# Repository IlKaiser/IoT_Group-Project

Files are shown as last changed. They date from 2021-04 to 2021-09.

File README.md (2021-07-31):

# Safety Floater

## Team Members

The team is composed by:
- Daniele Bufalieri [Linkedin Profile](https://www.linkedin.com/in/daniele-bufalieri-4b245a121/)
- Marco Calamo  [Linkedin Profile](https://www.linkedin.com/in/marco-calamo-9766751a3/)
- Ivan Giacomoni [Linkedin Profile](https://www.linkedin.com/in/ivan-giacomoni-53100420a/)

## Main Idea

**Safety Floater** is a smart floater with the purpose to detect the **illegal transit** of the **boats** near by swimmers, in order to preserve the safe distance. This system allows to the authorities to monitor coasts and tourists' welfare. At the same time, Safety Floater allows achieve another goal in an indirect way: improve the water pollution near the coast.

In future, the system could be used to monitor the state of the sea and to improve the prevention of the illegal traffic of boats by installing a camera in order to get a photo of who break the rules.

## Documents

- [Concept](https://github.com/IlKaiser/IoT_Group-Project/blob/main/concept.md)
- [Technology](https://github.com/IlKaiser/IoT_Group-Project/blob/main/technology.md)
- [Evaluation](https://github.com/IlKaiser/IoT_Group-Project/blob/main/evaluation.md)

## Circuit

More informations about the **circuit** and the whole **wiring of components** can be found [here](https://github.com/IlKaiser/IoT_Group-Project/blob/main/circuit/README.md).

## Setup

More informations about the **setup** of the project can be found [here](https://github.com/IlKaiser/IoT_Group-Project/blob/main/setup.md).

## Code

- **Nucleo code**: more info about the Nucleo code can be found [here](https://github.com/IlKaiser/IoT_Group-Project/blob/main/nucleo_code/README.md).
- **Arduino code**: more info about the Arduino code can be found [here](https://github.com/IlKaiser/IoT_Group-Project/blob/main/arduino_code/README.md).
- **Raspberry code**: more info about the Raspberry code can be found [here](https://github.com/IlKaiser/IoT_Group-Project/blob/main/raspberry_code/Code.md).
- **Convolutional Neural Network code**: more info about the Convolutional Neural Network code can be found [here](https://github.com/IlKaiser/IoT_Group-Project/blob/main/ML/MR-SSD.md).

## Web Dashboard

More informations about the **Web Dashboard** can be found [here](https://github.com/IlKaiser/IoT_Group-Project/blob/main/dashboard/README.md).

## Evaluation on Iot-lab

More informations about the **evaluation** conducted on [Iot-lab](https://www.iot-lab.info/) can be found [here](https://github.com/IlKaiser/IoT_Group-Project/blob/main/evaluation/README.md).

## Videos

- [Presentation of the project](https://www.youtube.com/watch?v=rqtzGxGxrBQ)
- [Demo](https://youtu.be/sozL5CH4RoQ)

## Blog post

[Blog post](https://medium.com/@danielebufalieritkd/safety-floater-1a63ddf3e4a9)

## Releases

- [First delivery](https://github.com/IlKaiser/IoT_Group-Project/releases/tag/1.0): for the first delivery you can also check this set of [slides](https://github.com/IlKaiser/IoT_Group-Project/blob/main/Safety%20floater.pptx)
- [Second delivery](https://github.com/IlKaiser/IoT_Group-Project/releases/tag/2.0): for the second delivery you can find more info [here](https://github.com/IlKaiser/IoT_Group-Project/blob/main/2nd_delivery.md), and you can also check this set of [slides](https://github.com/IlKaiser/IoT_Group-Project/blob/main/Safety%20floater_2nd_delivery.pptx)
- [Third delivery](https://github.com/IlKaiser/IoT_Group-Project/releases/tag/3.0): for the third delivery you can also check this set of [slides](https://github.com/IlKaiser/IoT_Group-Project/blob/main/Safety%20floater_final_delivery.pptx)

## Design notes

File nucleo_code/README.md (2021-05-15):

# Nucleo code

## Starting the application
The application starts by initializing the I2C interface. In order to do this, we need to add the *periph_i2c* feature in the [Makefile](https://github.com/IlKaiser/IoT_Group-Project/blob/main/nucleo_code/Makefile):

### I2C initialization

```c
FEATURES_REQUIRED += periph_i2c
```

Also, we need to include the following **headers** in the [main.c](https://github.com/IlKaiser/IoT_Group-Project/blob/main/nucleo_code/main.c):

```c
#include "periph_conf.h"
#include "periph/i2c.h"
```

Also we have to define the I2C interface:

```c
#define I2C_INTERFACE I2C_DEV(0)
```

Below we report the code related to the initialization of the I2C interface:

```c
//initialize the i2c interface
i2c_init(I2C_INTERFACE);
```
### I2C communication
Finally, the I2C communication is managed by the *I2CCommunication* function:

```c
void I2CCommunication(int cmd,void*buffer,int len,char* service){
    mutex_lock(&mutex);
    while(i2c_acquire(I2C_INTERFACE)<0)
	printf("[%s]ERROR ACQUIRING \n",service);
    if(i2c_write_byte(I2C_INTERFACE,ARDUINO_ADDRESS,cmd,0)<0)
	printf("[%s] ERROR WRTITING \n",service);
    if(i2c_read_bytes(I2C_INTERFACE,ARDUINO_ADDRESS,buffer,len,0)<0)
	printf("[%s] READING \n",service);
    i2c_release(I2C_INTERFACE);
    mutex_unlock(&mutex);	
}
```

As we can see we need to define the **Arduino address** in the [main.c](https://github.com/IlKaiser/IoT_Group-Project/blob/main/nucleo_code/main.c):

```c
#define ARDUINO_ADDRESS (0X04)
```

Notice how the access to the I2C bus is treated as a **critical section**, because we have to avoid that multiple threads access it at the same time. In order to do this, we used a **mutex**, so we have to include the following **header** in the [main.c](https://github.com/IlKaiser/IoT_Group-Project/blob/main/nucleo_code/main.c):

```c
#include "mutex.h"
```

We define the mutex as follows:

```c
//define mutex to protect i2c access
mutex_t mutex;
```

### Threads
Then we create three different threads, one for each sensor we used:

```c
thread_create(stackThreadAlarm,sizeof(stackThreadAlarm),THREAD_PRIORITY_MAIN,0,threadAlarm,NULL,"Thread Alarm detection");
	printf("Thread proximity alarm created! \n");
	
thread_create(stackThreadControl,sizeof(stackThreadControl),THREAD_PRIORITY_MAIN,0,threadControl,NULL,"Thread Control");
	printf("Thread control created! \n");
	
thread_create(stackThreadInfo,sizeof(stackThreadInfo),THREAD_PRIORITY_MAIN,0,threadInfo,NULL,"Thread Info ");
	printf("Thread info created! \n");
```

In order to do this we need to include this **header** in the [main.c](https://github.com/IlKaiser/IoT_Group-Project/blob/main/nucleo_code/main.c):

```c
#include "thread.h"
```

## Pins initialization
All pins used are initialized by using the **GPIO peripheral driver**, that maps each pin to a **port** with a certain **port number**. Particularly, all mappings are shown in the picture below:

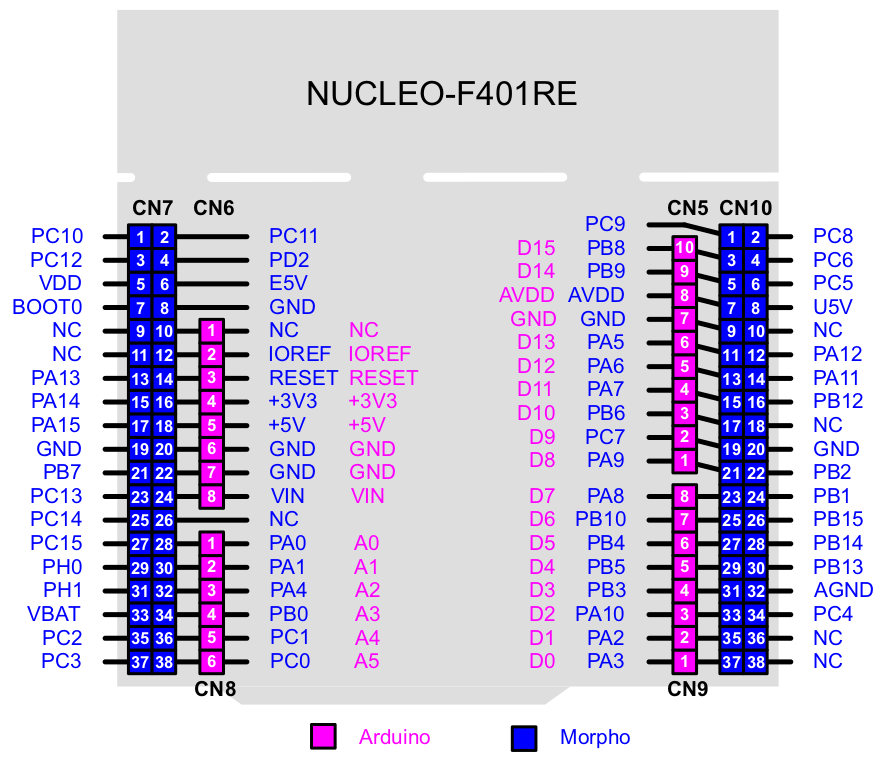
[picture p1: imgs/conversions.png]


## Alarm thread

This thread initializes the **buzzer**, and then starts periodically requesting the Arduino info about the current situation nearby the floater by the **I2C communication**. If the Nucleo receives a number of indications of a possible violation greater or equal than a certain **ALARM_THRESHOLD**, then the buzzer starts to sound and a **notification** that a boat was found is sent to the Arduino by the I2C communication.
The buzzer is initialized in this way:

### Alarm thread: buzzer

```c
//definition and initialitation of buzzer using pin D9
gpio_t buzzer;

buzzer=GPIO_PIN(PORT_C,7);
if(gpio_init(buzzer,GPIO_OUT)<0){
    printf("[ALARM]Error during buzzer initialitation!\n");
    return NULL;
}
```

It is managed by the *controlBuzzer* function:

```c
void controlBuzzer(gpio_t buzzer,int status){
    if(status==0)
	gpio_clear(buzzer);
    else if(status==1)
	gpio_set(buzzer);
}
```

### Alarm thread: periodical sampling

The periodical requests are done by using the **xtimer** module, so we need to specify it in the [Makefile](https://github.com/IlKaiser/IoT_Group-Project/blob/main/nucleo_code/Makefile):

```c
USEMODULE += xtimer
```

Also, we need to include this **header** in the [main.c](https://github.com/IlKaiser/IoT_Group-Project/blob/main/nucleo_code/main.c):

```c
#include "xtimer.h"
```

We define the **base sampling period** for the Alarm thread as follows:

```c
#define DELAY_ALARM_BASE 1

int delay_alarm = DELAY_ALARM_BASE;
```

### Alarm threshold
The **alarm threshold** is defined as follows:

```c
#define ALARM_THRESHOLD 2
```

### Alarm thread: I2C communication
Given that the *I2CCommunication* function takes as input the **command** related to the specific request for the Arduino, the **buffer** for receiving data from the I2C bus, the **length** of the buffer and the specific **service**, we need to specify the **command** and **buffer length** for both cases of use of the I2C communication by the Alarm thread:

```c
#define ALARM_BUFFER_SIZE 1
#define ALARM_CMD 1
#define BOAT_FOUND_CMD 5
```

### Alarm thread: periodical requests
So, the **periodical request** of the alarm thread is resumed in the following code:

```c
int cont=0;
char buffer[ALARM_BUFFER_SIZE]={0};
	
while(1){
	I2CCommunication(ALARM_CMD,buffer,ALARM_BUFFER_SIZE,"ALARM");
	printf("[ALARM]MEX: %s \n",buffer);
		
	if(atoi(buffer)==1)
		cont++;
	else
		cont=0;

	if(cont==ALARM_THRESHOLD){
		controlBuzzer(buzzer,1);
		I2CCommunication(BOAT_FOUND_CMD,buffer,ALARM_BUFFER_SIZE,"BOAT FOUNDs");
	}
	if(cont==0)
		controlBuzzer(buzzer,0);
		
	xtimer_sleep(delay_alarm);
	
}
```

## Control thread

### Control thread: MPU-9250 initialization
The thread first initialize the **MPU9250 sensor**, then periodically samples it in order to check, together with the Arduino, whether the **proximity sensor** needs to be better oriented or not, and also to manage the **power consumption** in a smart way.
In order to use the MPU9250 sensor we have to specify the **mpu9250 module** in the [Makefile](https://github.com/IlKaiser/IoT_Group-Project/blob/main/nucleo_code/Makefile):

```c
# MPU-9250 driver
DRIVER ?= mpu9250
USEMODULE += $(DRIVER)
```

Also, we need to include some **utilities** in the [Makefile](https://github.com/IlKaiser/IoT_Group-Project/blob/main/nucleo_code/Makefile):

```c
# utilities for MPU 
ifneq (,$(wildcard $(CURDIR)../../RIOT/tests*/.))
  DEFAULT_MODULE += test_utils_interactive_sync
  # add interactive test configuration when testing Kconfig
  ifeq (1,$(TEST_KCONFIG))
    KCONFIG_ADD_CONFIG += $(RIOTBASE)/tests/test_interactive.config
  endif
endif

ifneq (,$(filter tests_driver_%,$(APPLICATION)))
  BOARD ?= nucleo-f401re
endif
```

Also, we need to include the following **headers** in the [main.c](https://github.com/IlKaiser/IoT_Group-Project/blob/main/nucleo_code/main.c):

```c
#include "mpu9x50.h"
#include "mpu9x50_params.h"
```

Then we have to specify the **buffer length** for the control thread for the I2C communication with Arduino:

```c
#define CONTROL_BUFFER_SIZE 10
```

The MPU9250 is initialized as follows:

```c
char buffer[CONTROL_BUFFER_SIZE]={0};
		
// definition of MPU-device
mpu9x50_t dev;
int result;

// MPU device initialization
result = mpu9x50_init(&dev, &mpu9x50_params[0]);
    
// Check errors
if (result == -1) {
    puts("[MPU9250] The given i2c is not enabled");
    return NULL;
}
else if (result == -2) {
    puts("[MPU9250] The compass did not answer correctly on the given address");
    return NULL;
}
   
// Definition of sample rates
mpu9x50_set_sample_rate(&dev, 200);
if (dev.conf.sample_rate != 200) {
    puts("[MPU9250] The sample rate was not set correctly");
    return NULL;
}
    
mpu9x50_set_compass_sample_rate(&dev, 100);
    
if (dev.conf.compass_sample_rate != 100) {
    puts("[MPU9250] The compass sample rate was not set correctly");
    //return NULL;
}
```

### Control thread: periodical sampling
We define the **base sampling period** for the Control thread as follows:

```c
#define DELAY_CONTROL_BASE 100

int delay_control = DELAY_CONTROL_BASE;
```

So, the **periodical sampling** of the control thread is resumed in the following code:

```c
short x_start_compass = 0;
	
//sample values for magnetic field detected by the compass and accelerometer
short z_gyro, x_compass, z_accel;
	
getControlData(dev, &z_gyro, &x_start_compass, &z_accel);
		
int last_state = 0;  // It stands for 'the proximity sensor is correctly orientated'

while(1){
	//get control data correction degree will be saved into buffer with sintax -360/360 as char*
	getControlData(dev, &z_gyro, &x_compass, &z_accel);
				
	// Proximity sensor correction
	proximitySensorCorrection(buffer, x_start_compass, x_compass, z_gyro, &last_state);
		
	// Power management
	float z_accell = ( (float) z_accel ) * GRAVITY_ACCELERATION / 1000;
	powerManagement(z_accell);
		
	xtimer_usleep(delay_control);
}
```

### Control thread: getControlData function
As we can see, data from MPU9250 are retrieved by using the *getControlData* function. Below we show the code related to this function:

```c
void getControlData(mpu9x50_t dev, short* z_gyro, short* x_compass, short* z_accel)
{
	//Data structure to save info
	mpu9x50_results_t measurement;
    
	mutex_lock(&mutex);
	
	/* Get accel data in milli g */
        mpu9x50_read_accel(&dev, &measurement);
        *z_accel = measurement.z_axis;
        //printf("[MPU9250] Accel data [milli g] - X: %"PRId16"   Y: %"PRId16"   Z: %"PRId16"\n",
        //        measurement.x_axis, measurement.y_axis, measurement.z_axis);
        /* Get gyro data in dps */
        mpu9x50_read_gyro(&dev, &measurement);
        *z_gyro = measurement.z_axis;
        //printf("[MPU9250] Gyro data [dps] - X: %"PRId16"   Y: %"PRId16"   Z: %"PRId16"\n",
        //        measurement.x_axis, measurement.y_axis, measurement.z_axis);
        /* Get compass data in mikro Tesla */
        
        while(!first_read_compass_done){
			
		mpu9x50_read_compass(&dev, &measurement);
		*x_compass = measurement.x_axis;
		    
		if(*x_compass != 0){
			first_read_compass_done = 1;
			break;	
		}	
	}
		
	if(first_read_compass_done){
		mpu9x50_read_compass(&dev, &measurement);
		*x_compass = measurement.x_axis;	
	}

	mutex_unlock(&mutex);
	
}
```

Notice that each sampling from the MPU9250 is treated as a **critical section**, because the sensor communicates with the Nucleo board by I2C, so we have to use the **mutex** in order to avoid **starvations** of other threads.

### Control thread: proximitySensorCorrection function

```c
void proximitySensorCorrection(char* buffer, short x_start_compass, short x_compass, short z_gyro, int* last_state){
    float degree = calculateDegreeFromDps(z_gyro, FIXED_NUMBER);
    
	short x_diff_compass = x_start_compass - x_compass;	
	int x_diff_compass_abs = abs((int)x_diff_compass);
	
	// If the proximity sensor is NOT correctly orientated
	if(x_diff_compass_abs > CORRECTION_THRESHOLD){
		
		// If it was correctly orientated before this point
		if(*last_state == 0){
		    
		    // If it is moving to the left 
		    if(degree > 0){
			    
			    // Setting the last state to 1, which means that the "next" last state will be that
			    // the proximity sensor was moved to the right
			    *last_state = 1;
			    // Send to Arduino the indication to move it to the right
			    I2CCommunication(CONTROL_CMD_RIGHT, buffer, CONTROL_BUFFER_SIZE, "CONTROL");
			        	
			}
			
			// If it is moving to the right
			else if(degree < 0){
			    
			    // Setting the last state to 2, which means that the "next" last state will be that
			    // the proximity sensor was moved to the left
			    *last_state = 2;
			    // Send to Arduino the indication to move it to the left
			    I2CCommunication(CONTROL_CMD_LEFT, buffer, CONTROL_BUFFER_SIZE, "CONTROL");
			        	
			} 
		    	
		}
		
		// If it was moved to the rigth before this point
		else if(*last_state == 1){
			
		    // Send to Arduino the indication to move it to the right
			I2CCommunication(CONTROL_CMD_RIGHT, buffer, CONTROL_BUFFER_SIZE, "CONTROL");
		}
		
		// If it was moved to the left before this point
		else if(*last_state == 2){
			
		    // Send to Arduino the indication to move it to the left
			I2CCommunication(CONTROL_CMD_LEFT, buffer, CONTROL_BUFFER_SIZE, "CONTROL");
		}
		
	}
	
	// The proximity sensor is correctly orientated
	else{
		*last_state = 0;
	    //printf("The proximity sensor is correctly orientated\n"); 
	}
		
}
```

The main idea of the proximity sensor orientation correction is measuring the first value of the **magnetic field (in µT)** along the **x-axis** of the **compass**, and continuosly check whether the current value measured is too far from the starting value, for example by exploiting a **correction threshold**, that we define in the [main.c](https://github.com/IlKaiser/IoT_Group-Project/blob/main/nucleo_code/main.c) as follows:

```c
#define CORRECTION_THRESHOLD 1
```

If the current orientation of the proximity sensor is too far from the starting one, then we send to Arduino by I2C the indication to rotate the sensor in the opposite direction from the currently detected motion, that is detected by the the measurement of the **dps (degree per seconds)** along the **z-axis** of the **gyroscope**. This procedure is repeated until the proximity sensor is not correctly orientated again. We have also to define, in the [main.c](https://github.com/IlKaiser/IoT_Group-Project/blob/main/nucleo_code/main.c), the two commands for the I2C communication, indicating a correction towards the right or the left:

```c
#define CONTROL_CMD_RIGHT 2
#define CONTROL_CMD_LEFT 3
```

### Control thread: power management

The **power management** is handled by the sampling of the **acceleration** measured along the **z-axis** of the **accelerometer**:

- if the acceleration is below a **low threshold**, then sampling delays are setted to the base delays
- if the acceleration is above a **low threshold** but below an **high threshold**, then sampling delays are slightly increased
- if the acceleration is above a **high threshold**, then sampling delays are further increased

So we have to define the **thresholds** in the [main.c](https://github.com/IlKaiser/IoT_Group-Project/blob/main/nucleo_code/main.c):

```c
#define LOW_PM_THRESHOLD 9.5
#define HIGH_PM_THRESHOLD 10.0
```

Also, we have to define all **delays** in the [main.c](https://github.com/IlKaiser/IoT_Group-Project/blob/main/nucleo_code/main.c):

```c
//medium time interval for each thread
#define DELAY_INFO_MEDIUM 50
#define DELAY_ALARM_MEDIUM 10
#define DELAY_CONTROL_MEDIUM 10000000

//high time interval for each thread
#define DELAY_INFO_HIGH 70
#define DELAY_ALARM_HIGH 20
#define DELAY_CONTROL_HIGH 60000000
```

All this is done by the *powerManagement* function:

```c
void powerManagement(float z_accel){
    if(z_accel <= LOW_PM_THRESHOLD){
		printf("ACCEL LOW!\n");
		    
		delay_alarm = DELAY_ALARM_BASE;
		delay_control = DELAY_CONTROL_BASE;
		delay_info = DELAY_INFO_BASE;	
    }
    
    else if(z_accel > LOW_PM_THRESHOLD && z_accel <= HIGH_PM_THRESHOLD){
		printf("ACCEL MEDIUM!\n");
		    
		delay_alarm = DELAY_ALARM_MEDIUM;
		delay_control = DELAY_CONTROL_MEDIUM;
		delay_info = DELAY_INFO_MEDIUM;	
    }
		
    else if(z_accel > HIGH_PM_THRESHOLD){
		printf("ACCEL HIGH!\n");
		    
		delay_alarm = DELAY_ALARM_HIGH;
		delay_control = DELAY_CONTROL_HIGH;
		delay_info = DELAY_INFO_HIGH;	
     }
}
```

## Info thread

This thread periodically requests the Arduino for the **last known position** of the floater. In the [main.c](https://github.com/IlKaiser/IoT_Group-Project/blob/main/nucleo_code/main.c), we need to define the **base sampling period** for the Info thread as follows:

```c
#define DELAY_INFO_BASE 30

int delay_info = DELAY_INFO_BASE;
```

Also, in the [main.c](https://github.com/IlKaiser/IoT_Group-Project/blob/main/nucleo_code/main.c), we need to define the **buffer length** for the I2C communication with Arduino, as well as the **info command**:

```c
#define INFO_BUFFER_SIZE 20
#define INFO_CMD 4
```

### Info thread: periodical requests
So, the **periodical requests** of the **Gps** informations done by the Info thread are resumed in the following code:
```c
char buffer[INFO_BUFFER_SIZE]={0};
while(1){	
	
	I2CCommunication(INFO_CMD,buffer,INFO_BUFFER_SIZE,"INFO");
		
	char* first = getSubstr(buffer, 0, 2);
		
	if(strcmp(first, "/") == 0){
		printf("[INFO] No info received!\n");
	}
		
	else{
		printf("[INFO] %s\n",buffer);
	}
			
	xtimer_sleep(delay_info);
	
}
```

Obviosuly, gps info could not be immediately available.

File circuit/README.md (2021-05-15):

# Wiring of components
For the project we will use:
- an [STM32 Nucleo-64 F401RE](https://www.st.com/en/evaluation-tools/nucleo-f401re.html) board
- an [Arduino Uno](https://store.arduino.cc/arduino-uno-rev3) board
- a [Raspberry Pi 4](https://www.raspberrypi.org/products/raspberry-pi-4-model-b/) board
- 1 HC-SR04 ultrasonic proximity sensor
- an MPU-9250 9 Axis Gyroscope Accelerometer Magnetic Field sensor
- a BN-880 gps module
- a Raspberry pi Camera Rev 1.3
- 1 buzzer
- 1 100 Ohm resistor
- 1 Stepper Unipolar motor
- 1 ULN2008
- 1 HC-05

First, we need to put the **5v supply** and the **ground** on the breadboard.

In order to establish the **I2C** communication between the Nucleo board and the Arduino Uno board, we need to:
- connect one **GND pin** of the Arduino Uno board with one **GND pin** of the Nucleo board
- the **A5 pin** of the Arduino Uno board with the **SCL/D15 pin** of the Nucleo board
- the **A4 pin** of the Arduino Uno board with the **SDA/D14 pin** of the Nucleo board

However, since the SCL and SDA pins are also needed for the MPU-9250 sensor, we need to put them on the breadboard.

Now we explain the wiring of sensors and actuators:
- For the **buzzer**, we have to use a **resistor of 100 Ohm**, and we need to connect the **positive pin** of the buzzer to a **digital pin** of the Nucleo board, while the **negative pin** will be connected to one side of the resistor, and finally the other side of the resistor will be connected to **ground**: particularly, the digital pin of the Nucleo board we connect the buzzer is the **D9 pin**
- For the **HC-SR04** sensor we need to connect the **GND pin** to **ground** on the breadboard, the **VCC pin** to **5V** on the breadboard, the **trig pin** to the **D12 pin** of the Arduino Uno board and the **echo pin** to the **D13 pin** of the Arduino Uno board
- For the **MPU-9250** sensor we need to connect the **GND pin** to **ground** on the breadboard, the **VCC pin** to **3.3V** of the Nucleo board, the **SCL pin** to the **SCL/D15 pin** of the Nucleo board on the breadboard and the **SDA pin** to the **SDA/D14 pin** of the Nucleo board on the breadboard
- For the **BN-880** module we need to to connect the **GND pin** to **ground** on the breadboard, the **VCC pin** to **5V** on the breadboard and the **TX pin** to the **D7 pin** of the Arduino Uno board
- For the **HC-05** Bluetooth module we need to connect the **GND pin** to **GND** on Arduino, the **VCC pin** to **5V** of the Arduino board, the **RX pin** to the **D2 pin** of the Arduino board,the **TX pin** to the **D3 pin** of the Arduino board 

Below we can see the **wiring of components** for the Nucleo board and the Arduino Uno board:

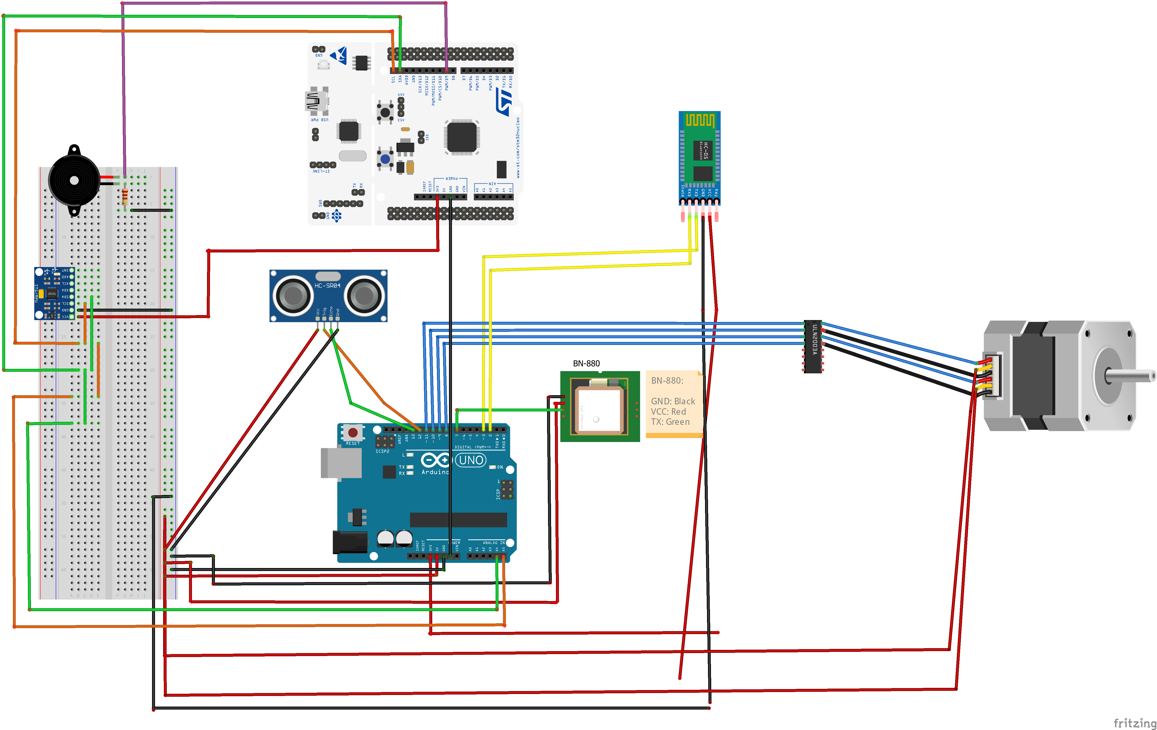
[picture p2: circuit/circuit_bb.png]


**NOTE!** As you can see from the wiring, we need to point out a few things: 
- the MPU sensor is not an MPU-9250 in the picture, but is an MPU-6050 sensor, that works with the same logic
- in the picture we have a 220 Ohm resistor but, as mentioned before, it should be a 100 Ohm resistor

Below we can see the **wiring of components** for the Raspberry board:

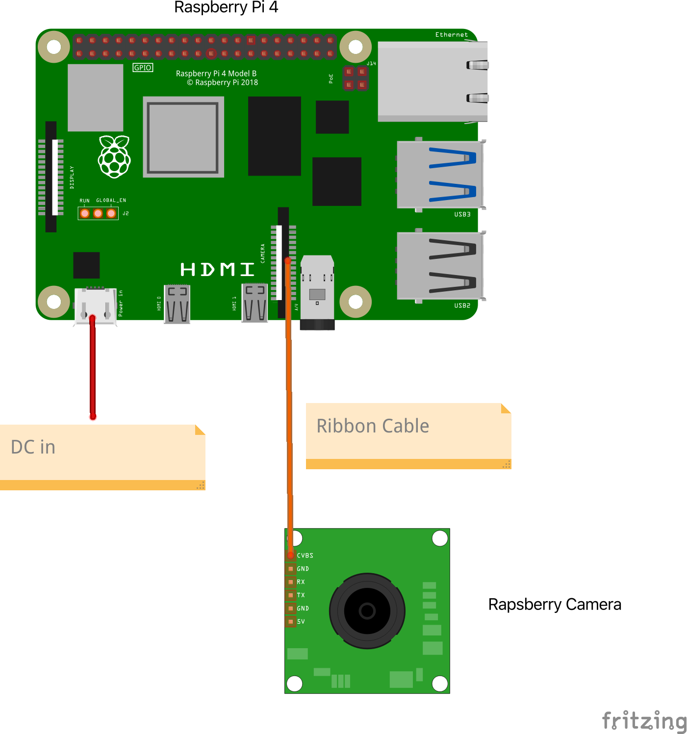
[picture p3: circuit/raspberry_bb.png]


No special wiring is required, the ribbon cable included with the camera needs to be installed in correct way in the camera slot.
Since the Raspberry will be in **Headless Mode** (will be entirely controlled remotely) only a generic 15W USB Type-C power supply is required.

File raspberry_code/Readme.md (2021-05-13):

# Raspberry Setup

## Before you start 
- Make sure you download the prebuilt .h5 model for machine learning from [here](https://drive.google.com/file/d/1-JYH7f6np6WcKjgFJ4iTFM7xC8h3vFz8/view?usp=sharing), you rename it **model.h5**
and you place it in the model folder
- Make sure to get aws **root certificate** (rootCA.pem), your **certificate** (cert.pem) and **private key** (private.key) for IoT Core and place it in certificates folder (more info [here](https://docs.aws.amazon.com/iot/latest/developerguide/iot-moisture-create-thing.html))
- Install pip requirements

## Install pip requirements
Run:
```
pip3 install -r requirements.txt
```
to automatically install all needed modules.
If you have issue installing tensorflow follow this [guide](https://qengineering.eu/install-tensorflow-2.4.0-on-raspberry-64-os.html), delete tensorflow from requirements and run the command again.

## Before you execute the program
### Bluetooth setup
Execute:
```
sudo rfcomm connect 0 <MAC of Bt adapter>
```
to connect the Arduino Bluetooth-Adapter tio Raspberry and Setup hc-05 serial protocol.

## Start program
```
python3 main.py
```
more info on the code [here](./Code.md).

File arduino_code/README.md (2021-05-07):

# Arduino code

## Libraries

- **Wire.h**: used to send messagges over the I2C bus towards the Nucleo board
- **Stepper.h**: used to manage the Stepper motor
- **TinyGPS.h**: used to parse data received from the gps module
- **SoftwareSerial.h**: used for the serial connection with the GPS device and the Bluetooth module

In order to use them, we need to include them on the top of the [sensors.ino](https://github.com/IlKaiser/IoT_Group-Project/blob/main/arduino_code/sensors.ino):

```cpp
#include <Wire.h>
#include <Stepper.h>
#include <TinyGPS++.h>
#include <SoftwareSerial.h>
```

## Macro

- **trigPin**: it specifies the trig pin of the HCSR04 ultrasonic proximity sensor, whose purpose is to trigger the ultrasound
- **echoPin**: it specifies the echo pin of the HCSR04 ultrasonic proximity sensor, whose purpose is to receive the signal back from the object detected
- **SMART_DELAY_GPS**: it indicates (in ms) the delay after which the gps object tries to read new data
- **STEPS**: number of steps performed by the Stepper motor
- **MAX_DISTANCE_FROM_FLOATER**: under this threshold (in cm), the Arduino board send a notification of a possible detection to the Nucleo board

So we need do define these constants in the [sensors.ino](https://github.com/IlKaiser/IoT_Group-Project/blob/main/arduino_code/sensors.ino):

```cpp
#define trigPin                       12
#define echoPin                       13
#define SMART_DELAY_GPS               50
#define STEPS                         48
#define MAX_DISTANCE_FROM_FLOATER     170   
```

## Global variables

- **mode**: auto or test, default is auto
- **ID**: the floater id
- **x**: a byte used to discriminate between the different type of requests recieved by the Nucleo board
- **durata, cm**: used to store, respectively, the time it takes for the impulse to go and return and the distance (in cm) measured.
- **RXPin, TXPin**: RXPin and TXPin for the GPS
- **infoGps**: used to store info retrieved from the bn-880n gps module
- **ss**: SoftwareSerial instance for the serial connection to the GPS device
- **EEBlue**: SoftwareSerial instance for the serial connection to the Bluetooth module
- **gps**: the TinyGPS++ object
- **stepper**: instance of the stepper class

So we need do define these global variables in the [sensors.ino](https://github.com/IlKaiser/IoT_Group-Project/blob/main/arduino_code/sensors.ino):

```cpp
String mode = "auto";
String ID="1";
byte x = 0;
long durata, cm;
static const int RXPin = 7, TXPin = 3;
static const uint32_t GPSBaud = 9600;
String infoGps;
SoftwareSerial ss(RXPin, TXPin);
SoftwareSerial EEBlue(3, 2);
TinyGPSPlus gps;
Stepper stepper(STEPS, 8, 10, 9, 11);
```

## Setup function
We need to set the **Arduino address** in order to correctly establish the I2C communication with the Nucleo board:

```cpp
Wire.begin(0x04);
```

Then we need to set the **data rate** of both serial connections to **9600 bps**:

```cpp
EEBlue.begin(9600);
ss.begin(9600);
```

Then we need to specify that whenever on the I2C bus there is some data to read, we need to handle this event by executing the *receiveEvent* function:

```cpp
Wire.onReceive(receiveEvent);
```

Also, we need to specify that whenever the Nucleo board makes a specific request to the Arduino, we need to handle this event by executing the *requestEvent* function:

```cpp
Wire.onRequest(requestEvent);
```

Then we need to initialize the **pins** for the **HCSR04** sensor:

```cpp
pinMode(trigPin, OUTPUT);
pinMode(echoPin, INPUT);
```

## Loop function
The loop function is used only to periodically update (by using the *smartDelay* function) the **position** of the floater, by using the *getGpsInfo* function. Below I report these two functions:

```cpp
String getGpsInfo(){
  if(gps.location.isValid() && gps.speed.isValid()){

    float lat = gps.location.lat(), lon = gps.location.lng(), speed_kmh = gps.speed.kmph();
   
    String lat_s = fromFloatToString(lat, 4);
    String lon_s = fromFloatToString(lon, 4);
    float speed_ms = speed_kmh / 3.6;

    String info = "";
    info += String(lat_s);
    info += ";";
    info += String(lon_s);
    info += ";";
    info += String(speed_ms);
    
    return info;
  }

  else{
      return "/";
  }
}

static void smartDelay(unsigned long ms)
{
  unsigned long start = millis();
  do 
  {
    while (ss.available())
      gps.encode(ss.read());
  } while (millis() - start < ms);
}
```

## receiveEvent function
This function just store the type of request received by the Nucleo board that has to be done:

```cpp
void receiveEvent(int data){
  x = Wire.read();
}
```

## requestEvent function
This function manages the vaious type of requests received by the Nucleo board, with the possibility to use an **automatic** and a **test** mode. By looking the auto mode, we present the various type of requests' management.

### Boat detection (x==1)
By using the HCSR04 sensor, we send to the Nucleo board an indication of a **possible detection** if we are below the **MAX_DISTANCE_FROM_FLOATER** threshold, otherwise an indication that everything is ok. Below we report the code:

```cpp
if(x == 1){
        
        measureDistanceBy_HCSR04();
  
        Serial.print("Cm = ");
        Serial.println(cm);
        Serial.println();

        if(cm <= MAX_DISTANCE_FROM_FLOATER){
          Serial.println("Possible detection!");
          Wire.write("1");  
        }

        else{
          Serial.println("No boats detected!");
          Wire.write("0");    
        }

}
```

Also, we report the *measureDistanceBy_HCSR04* function:

```cpp
void measureDistanceBy_HCSR04(){
   
   digitalWrite(trigPin, LOW);
   delayMicroseconds(2);
   digitalWrite(trigPin, HIGH);
   delayMicroseconds(10);
   digitalWrite(trigPin, LOW);
   durata = pulseIn(echoPin, HIGH);
   cm = durata / 58;    // for inches the formula is duration / 148;
   
}
```

### Proximity sensor correction (x==2 || x==3)
By using the Stepper motor, we apply a **correction** of the proximiy sensor orientation towards the **right** if x is 2, otherwise towards the **left** if x is 3. Below we report the code for the correction towards the right, because the other one is similar:

```cpp
else if(x == 2){
        Serial.println("Received 2");

        int direction_ = -1, speed_ = 0;
        int val = 1023;

        speed_ = map(val, 0, 1023, 2, 500);
        // set the speed of the motor
        stepper.setSpeed(speed_);

        // move the stepper motor

        stepper.step(direction_);

        Wire.write("123");
        
}
```

### GPS (x==4)
By using the GPS module, we send to the Nucleo board, if available, the **last known position** of the floater. Below we show the code:

```cpp
else if (x == 4){
        if(infoGps == "/"){
          Wire.write("/");  
        }
    
        else{
          Wire.write(infoGps.c_str());  
        }
}
```

### Bluetooth (x==5)
By using the Bluetooth module, we send to Raspberry pi, if available, the **last known position** of the floater. Below we show the code:

```cpp
else if (x==5){
        if(infoGps!="/"){
          String toSend=infoGps+";"+ID;
          EEBlue.write(toSend.c_str());
        }
        else{
          EEBlue.write(ID.c_str());
        }
        Wire.write(x);
          
}
```

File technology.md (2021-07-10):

# Technology

## Core: Three main parts
- Safety Floater
- Sea Station
- Web Dashboard

### Safety Floater
It is the main component of our project: its main purpose is to detect **illegal transit of boats** over the safety line. When a violation is detected, the sensors data are sent to the **Sea Station (Ground server)**.
A **ultrasonic proximity sensor** is used for detections, a **gyroscope/compass** and a **stepper motor** grant that the floater has the proximity sensor correctly oriented, an **accelerometer** is used to provide a power management mechanism, **gps sensor** detects the current position of the floater, **solar panels** permit a longer battery life and **buzzer** is used for audio notification of swimmers.
A **LoraWan module** would be used in real life scenario to transmit data (its model in practice is a common **bluetooth module**).
The sensors are controlled by a [Nucleo Board](https://www.st.com/en/evaluation-tools/nucleo-f401re.html) (**nucleo-f401re**) with [RIOT OS](https://www.riot-os.org/), and measurements are made with an [Arduino Uno](https://store.arduino.cc/arduino-uno-rev3) board, because we have an easier integration of sensors.
The communication between the two boards is done with the **I2C protocol**: the Nucleo board is the **master**, it periodically asks for sensor data to the Arduino Uno, which is the **slave**. 
For more informations about the circuit, see [here](https://github.com/IlKaiser/IoT_Group-Project/blob/main/circuit/README.md).

### Sea station
It is the **ground server** of our system: it is a content aggregator of many Smart Floaters in a fixed range. It elaborates data from floaters and sends it to the remote server and database. Every Floater has a unique **id** for identification. It also notify the eventual violation to the Coast Guard.
We used a [Raspberry Pi](https://www.raspberrypi.org/products/raspberry-pi-4-model-b/) to take **pictures** of the possible violation, for a further evaluation with a **Convolutional Neural Network** in order to make sure whether there is an actual boat over the safety line or not. If an actual violation is detected, all data from the Floater are sent to **AWS** via **MQTT**.

### Web Dashboard
It is the highest level component of our project. It is composed by the **remote server** (using **AWS services and nodejs**) and by the frontend (web page realized with **HTML, Bootstrap, Javascript and Vue-JS**, and eventually an app). It displays the datas retrived from database (**DynamoDB**).

## Sensors
We chose our sensors based on our system requirements.

### MakerHawk MPU-9250 9DOF Module 9 Axis Gyroscope Accelerometer Magnetic Field Sensor


- 9-axis: 3-axis gyroscope + 3-axis accelerometer + 3-axis magnetic field sensor
- Power supply: 3-5v (low dropout internal regulator)
- Communication: standard IIC / SPI communication protocol
- 16-bit AD data output of the 16-bit chip converter
- Acceleration range: ± 2 ± 4 ± 8 ± 16g
- Magnetic field: ± 4800uT
- Using PCB Immersion Gold, soldering process to ensure quality
- Pin spacing: 2.54mm
- Module size: 15mm * 25mm

**Gyroscope/Compass** are used for **movement detection and orientation**, while **accelerometer** for **power management**.

### Ultrasonic Proximity Sensor HC-SR04


- Working Voltage: DC 5V
- Working Current: 15mA
- Working Frequency: 40Hz
- Max Range: 4m
- Min Range: 2cm
- Measuring Angle: 15 degree
- Trigger Input Signal: 10µS TTL pulse
- Echo Output Signal Input TTL lever signal and the range in proportion
- Dimension 45 * 20 * 15mm

It is used for **violation detection**.

### GPS BN-880
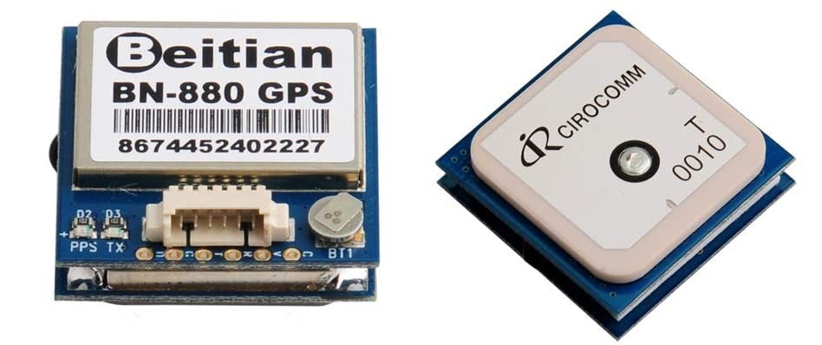
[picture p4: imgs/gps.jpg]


- GPS Module,Dual Module Compass
- With electronic compass IC HMC5883L
- 1.25mm spacing between the 6pins patch seat
- Receiving Format: GPS,GLONASS,Galileo,BeiDou,QZSS and SBAS
- Receiving Channel: 72 Searching Channel
- Output Frequency: 1Hz-10Hz,Default 1Hz
- Support Rate:4800bps to 115200bps,Default 38400dps
- UART Interface: UART Port: TXDA and RXDA
- Level Positioning Precison: 2m At Open Wind
- Speed Precison: 0.1 m/s (Without Aid)
- Acceleration Precison: 0.1 m/s (Without Aid)
- Power Supply: DC Voltage 2.8V~6.0V,Typical:3.3V or 5.0V
- Consumption: Capture 50mA@5V
- Working Temperature:-40℃-+85℃
- Storage Temperature:-40℃-+85℃
- Size:28mm x 28mm x 10mm
- Weight:10g

It is used for getting the last known **position** of the floater.

### Raspberry pi Camera Rev 1.3

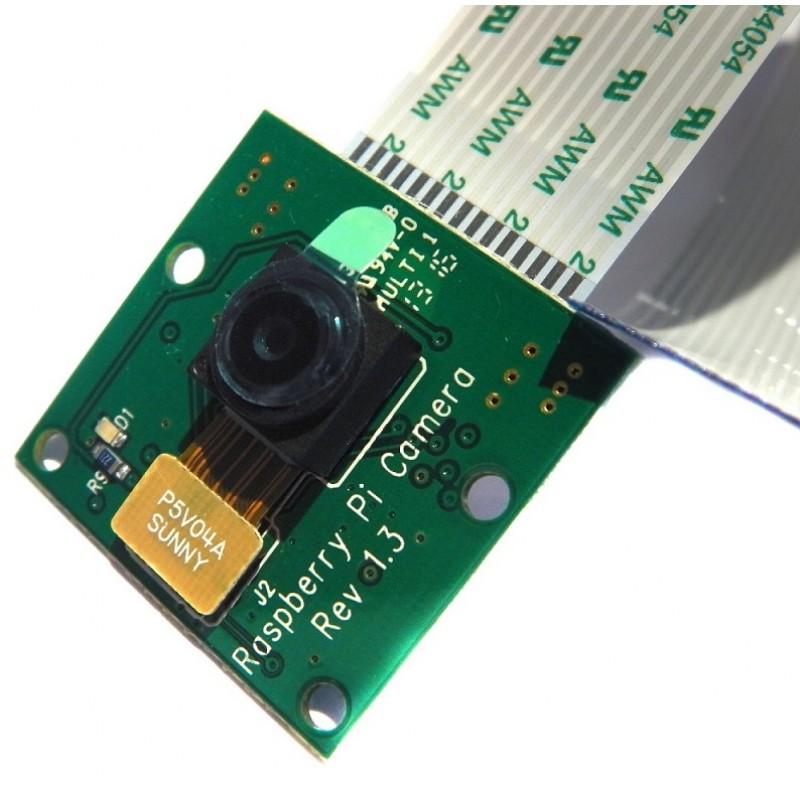
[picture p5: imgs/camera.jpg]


- Still resolution: 5 Megapixels
- Video modes: 1080p30, 720p60 
- Linux integration: V4L2 driver available
- C programming API: OpenMAX IL and others available
- Sensor: OmniVision OV5647
- Sensor resolution: 2592 × 1944 pixels
- Sensor image area: 3.76 × 2.74 mm
- Pixel size: 1.4 µm × 1.4 µm
- Optical size: 1/4"
- Full-frame SLR lens equivalent: 35 mm
- S/N ratio: 36 dB
- Dynamic range: 67 dB @ 8x gain
- Sensitivity: 680 mV/lux-sec
- Dark current: 16 mV/sec @ 60 C
- Well capacity: 4.3 Ke-
- Fixed focus: 1 m to infinity
- Focal length: 3.60 mm +/- 0.01
- Horizontal field of view: 53.50 +/- 0.13 degrees
- Vertical field of view: 41.41 +/- 0.11 degrees
- Focal ratio (F-Stop): 2.9

It is used to take **pictures** of the current situation, in order to check whether there is a **violation** or not.

## Actuators

### Buzzer



It is used for having a **sound notification** when a possible violation is detected.

### Stepper Motor



It is used for **correcting the orientation of the proximity sensor** with respect to the gyroscope/compass data.

Below we show an image of the spotter of the floater:

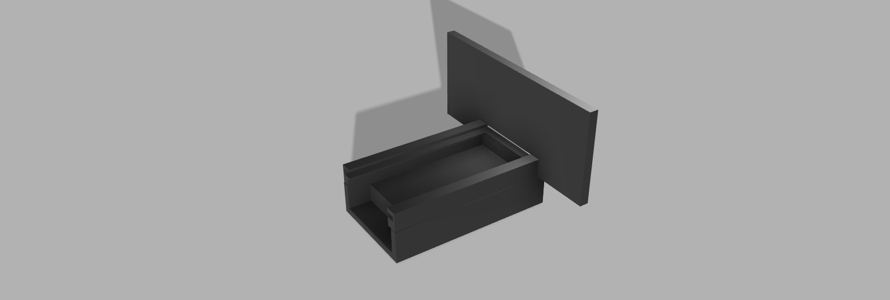
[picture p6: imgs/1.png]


## Communication

- **Smart Floater-to-Sea Station Communication** is via **LoraWan** in our original design, in practice we will use **Bluetooth**: in particular, we used an **HC-05 Bluetooth module**. Packets are sent with the status of the sensor if a possible violation is detected. 
- **Sea Station-to-Cloud Communication** via **MQTT** communication.

Below I show a picture of the HC-05 Bluetooth module:



## The final picture

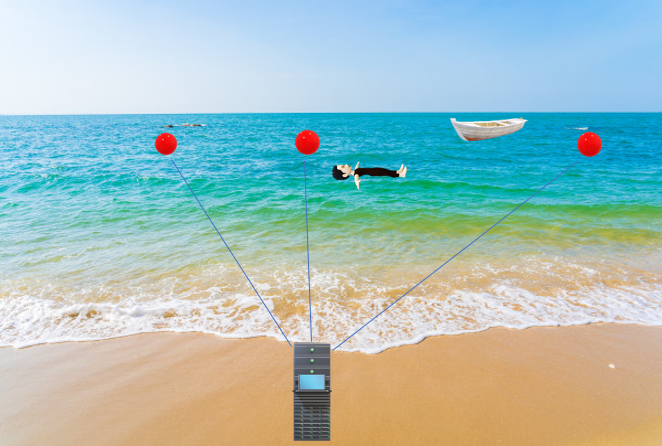
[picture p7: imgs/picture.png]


## Previous version
The previous version of the document can be found in the [previous release](https://github.com/IlKaiser/IoT_Group-Project/releases/tag/2.0) of the project.

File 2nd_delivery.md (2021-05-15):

# Second delivery

## Comments from first delivery
1. Studying sensors' performances in variuos situations, e.g. ultrasonic proximity sensor with temperature and humidity of air
2. Lora-WAN antenna dimensioning and positioning (how does the sea movement affects the performances of Lora-WAN protocol?)
3. How to solve the problem of detecting false positives that could derive from our solution
4. On Iot-lab, we need to develop a testing plan

Now for each of the previous points we explain our decisions:

1. In order to monitor the temperature and humidity of air we will use Weather Services API, notifying in case of very adverse measurements our floaters to enable the power safe mode.
2. Our use of Lora-WAN will be in the range of 150 metres, so the positioning and dimensioning of the antenna is not a relevant problem.
3. In order to solve this problem, the first approach is verifying if the detected object remains in the detection field for more than a fixed amount of seconds.
4. More info in the [evaluation.md](https://github.com/IlKaiser/IoT_Group-Project/blob/main/evaluation.md) document and in the [evaluation folder](https://github.com/IlKaiser/IoT_Group-Project/tree/main/evaluation).

## Changes

### Concept
No changes has been done.

### Architecture and technology
For the first delivery, our architecture was totally based on STM-32 devices. Now, since we wanted to use specific sensors (GPS, camera, other sensors) and we wanted to minimize the latency of the report notification, we changed slightly the architecture and the technology. Below we show a picture:

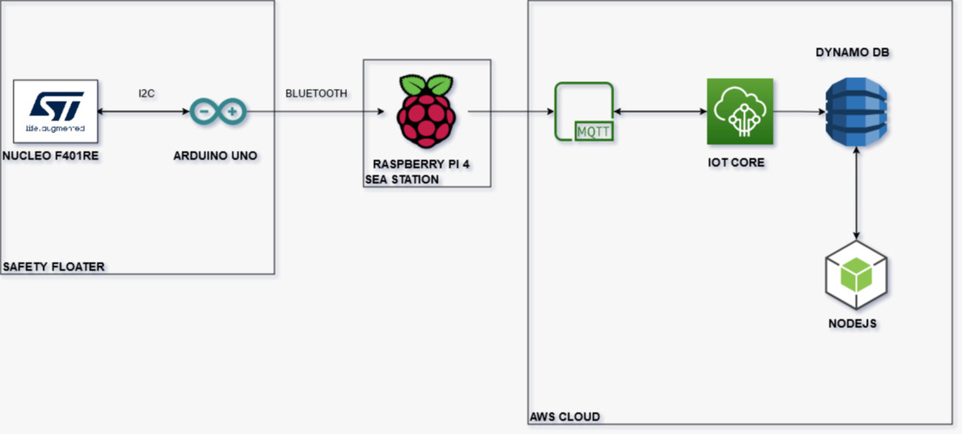
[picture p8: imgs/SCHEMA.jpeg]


Now we present the specific components.

#### Arduino-UNO
Attached to the Floaters, the [Arduino Uno](https://store.arduino.cc/arduino-uno-rev3) communicates with STM-32 with I2C protocol. It samples the GPS, the accelerometer and the proximity sensor. After sampling and some data-processing, it sends data to the STM-32 board.

#### STM-32
Attached to the Floaters, the [STM-32](https://www.st.com/en/evaluation-tools/nucleo-f401re.html) communicates with Arduino-UNO with I2C protocol. It manages actuators, which are the Stepper motor and the buzzer. It also uses Lora-WAN protocol to communicate with the Sea Station, in order to send data received by Arduino-UNO.

#### Sea Station (with Raspberry pi 4)
We decided to use a [Raspberry pi](https://www.raspberrypi.org/products/raspberry-pi-4-model-b/) for the Sea Station, because it is a portable device that offers great performances similar to a PC with low power consumption. It uses Lora-WAN protocol to communicate with the STM-32 board in order to receive reports and to take pictures, with the goal of verifying wheter there was a true violation or not, by using a Neural Network.

#### Cloud service
There are no changes for this part.

### Evaluation
More informations can be found [here](https://github.com/IlKaiser/IoT_Group-Project/blob/main/2nd_delivery.md#evaluation-1).

## Presentation of technical work
For the technical work, we present a list of the functionalities we implemented in different devices.

### Safety Floater
Safety Floater has been divided in two parts, so in two devices, that are the Arduino Uno board and the Nucleo Stm-32 board. The communication between them has been implemented with the I2C protocol, where the Nucleo board is the master and the Arduino Uno is the slave: in particular, the Nucleo board periodically sends request messages to the Arduino board, in order to retrieve informations about sensors and system. The functionalities provided are:

- **boat detection mechanism**: by using the ultrasonic proximity sensor and the buzzer, the system can detect whether a boat is transiting near the safety line or not. In order to avoid false positives, we introduced a smart measuring system based on delay
- **orientation control mechanism**: by using the gyroscope/compass and the stepper motor, we implemented a control system that is able to correct the orientation of the proximity sensor
- **power management mechanism**: by using the accelerometer, we implemented a power management system based on varying the sampling periods for sensors with respect to the acceleration measured by the accelerometer
- **system info mechanism**: by using the gps, we implemented a mechanism able to retrieve the last known position of the floater
- **sea-ground communication system**: we implemented the communication between the Safety Floater and the Sea Station by using a bluetooth module, in order to emulate Lorawan communication 

### Sea station
Sea station has been implemented with Raspberry pi, because we have no power management problems, and we need more computational power to handle the camera and the image recognition system. We have three main modules:

- **Ground-sea communication** via serial bluetooth, which receives data of a possible violation
- **Boat recognition system**, that takes pictures of the current situation and analyzes them with a Convolutional Neural Network in order to ensure that there is an actual violation and avoid false positives
- **Ground-cloud communication**, that periodically sends data of sensors to the cloud via MQTT if there is a violation

## Missing functionalities
- Optimizing power management
- Use a better gyroscope, if possible
- Improving latency
- Development of a better web interface
- Security

## Evaluation
For the evaluation:
- we estimated the **power consumption** of single subsytems
- we evaluated **performances of the CNN**
- we estimated the **latency** in the whole system
- we estimated the **correction accuracy** of the **stepper motor**.

## Evaluation for the 3rd delivery
We want to obtain the correct estimation of the previous parameters with the real prototype.

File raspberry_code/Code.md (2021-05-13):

#  Raspberry code explained

The code is dividied in modules, each for a specific task.

## Bluetooth module

Recieves an ecoded string with latiude, longitude, speed and floater id from Arduino with Bluetooth and hc05 protocol; decodes the string and returns the parsed value.
The main part is illustrated here:
```py
    bluetoothSerial = serial.Serial( "/dev/rfcomm0", baudrate=9600 )
    line = bluetoothSerial.readline()
   
    string = line.decode("utf-8")
    
    lat   = float(string.split(";")[0])
    long  = float(string.split(";")[1])
    speed = float(string.split(";")[2])
    floater_id    = int(string.split(";")[3])
    
    return lat,long,speed,floater_id

```

## Boat Detection module

The most important part of the program. It takes a picture with the Raspberry Camera and analyzes it with the CNN. If a Boat is detected returns True, else False.
```py
    # Start camera
    camera = PiCamera()
    camera.resolution = (2592, 1944)
    # Take pic
    print("Taking pic...")
    # Camera warm-up time
    sleep(2)
    camera.capture(photo_name)
    print("Pic taken,start processing...")

    # Tf analysis
    img = tf.keras.preprocessing.image.load_img('pic.jpg',target_size=(128,128))
    img_array = tf.keras.preprocessing.image.img_to_array(img)
    img_array = tf.expand_dims(img_array,0)
    predictions_single = model.predict(img_array)

    # Code Omitted [...]
    
    # Compute Response
    if response == 0:
        return False
    return True
```

## Drive Uploader module

Uploads taken picture on Drive and retrives link in order to add photo drive link to DB via Mqtt.
```py
        file_metadata = {'name': photo_name,'parents':["1euot5RlQOXgl7bV8yZWktXFMeZJ8HsuG"]}
        media = MediaFileUpload(photo_name, mimetype='image/jpeg',resumable=True)
        file = service.files().create(body=file_metadata,
                                        media_body=media,
                                        fields='id').execute()

        print("Upload Complete!")
        
        file_id = file.get('id')
        print("Upload of "+ photo_name+" succeded!")
        print('File ID: %s' % file_id)
        print("Setting permssions...")
        
        # Code Omitted [...]
       
        return file_id
```
## MQTT Publisher module

Publishes data taken from Bluetooth (latiude, longitude, speed and floater id) and drive file id to AWS Mqtt.
```py
    message = {"lat" : lat,"long": long,"speed" : speed,"floater_id": floater_id, "file_id": file_id }
    mqtt_connection.publish(topic=TOPIC, payload=json.dumps(message), qos=mqtt.QoS.AT_LEAST_ONCE)
    print("Published: '" + json.dumps(message) + "' to the topic: " + TOPIC)
   
```
## Main module
Puts all modules together:
- Waits for Bluetooth message to arrive for analysizing a possible violation
- Takes a picture and evaluates it with the pre-trained Neural Network
- If an actual violation is detected, Image of violation is uploaded to drive, and all useful informations are published to Mqtt

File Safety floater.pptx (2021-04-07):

## Safety floater

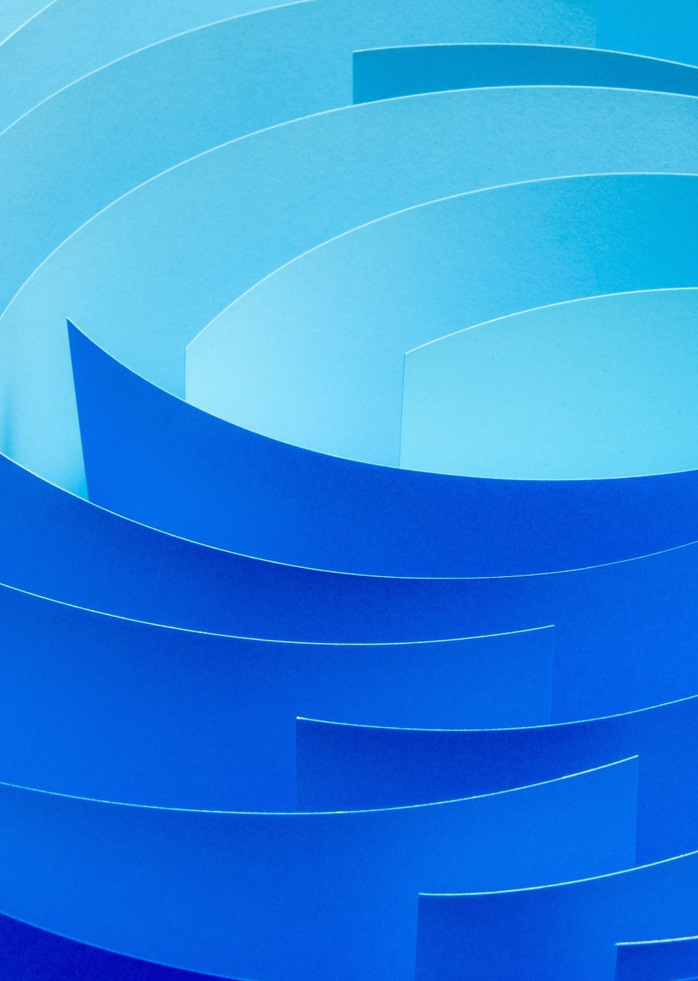
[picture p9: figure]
Primo piano di fogli di carta blu che formano un cerchio

IoT group project for coastal tourism

Blue Growth

Daniele Bufalieri, Marco Calamo, Ivan Giacomoni

## What is the problem?

- The problem is the security of swimmers because of the boats that do not respect the safety distance from the coast.
- It is a threat for the tourists and also for the environment because the pollution near the shore.
- There is not a direct communication to the authorities

## Boat accidents FROM 2002 TO 2019

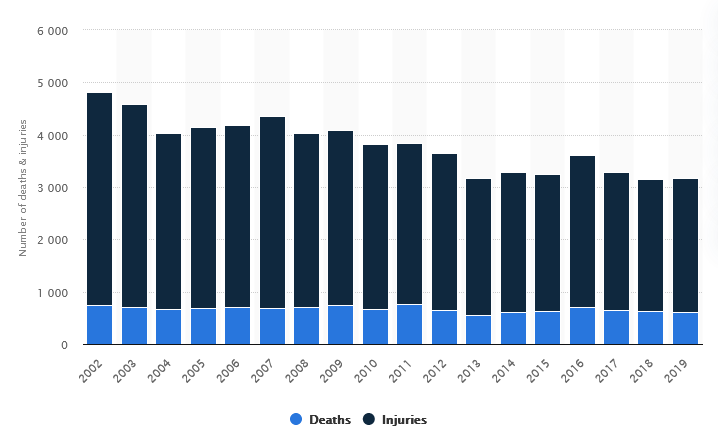
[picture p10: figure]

## Key functionalities

- Real time reporting to authorities of violations
- Create a safer holiday for tourists
- Improve water quality near the shore
- Decrease number of accidents
- Provide an user friendly dashboard in order to monitor violations

## Collective intelligence

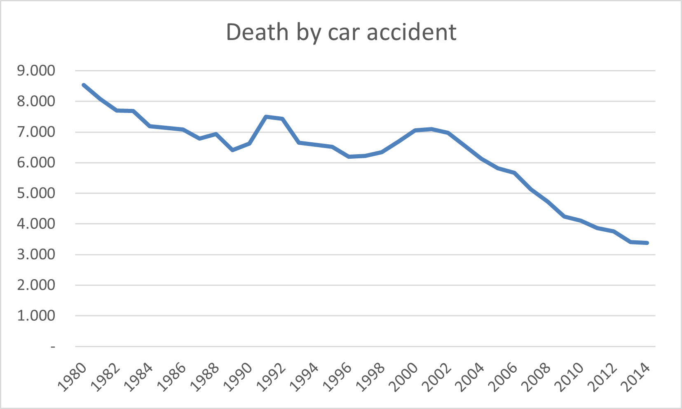
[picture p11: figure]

Our purpose is to replicate this trend of death by car accident since autovelox was introduced, but in the context of accident caused by boats introducing our system in order to prevent an increasing number of deaths.

## Iot architecture

Safety Floater

Sea Station

Cloud Server

Frontend

LoraWAN

MQTT

MQTT

REST

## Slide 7


- Red points represent Safety Floaters
- Server represents the Sea Station
- Blue links represent the communication
by LoraWAN

## Technology: safety floater

- It’s the key component: floater with sensors and actuators that monitor boats’ illegal transit
- The main board is NUCLEO STM32 F401RE with RIOT OS
- Sensors are proximity ultrasonic sensor SR04 for movement detection in water, 9-Axis magnetometer gyroscope accelerometer for orientation MPU-9250, GPS if possible
- Actuators are DC motors for correct orientations of SR04 and a buzzer for audio report
- Communications via LoraWAN to Sea Station with sensors data

## Technology: SEA STATION

- It is the bridge between the Cloud and Safety Floater, it is another NUCLEO STM32 F401RE board with RIOT OS
- It elaborates sensor data: if a violation is detected sends a notification via MQTT to IoT Core and takes pictures
- The notification is sent by MQTT through the violation topic while the data are saved into the cloud through the data topic

## Technology: CLOud server & FRONTEND

- Cloud Server is based on AWS, stores data from MQTT to DynamoDB
- Cloud Server hosts frontend on EC2 instance
- Frontend is developed in Javascript, Bootstrap, HTML, NodeJS and VueJS
- Frontend is designed for 2 kind of users: common users and coast guards
- Data are obtained by REST API

## Sensors & data collected

- MPU-9250 9DOF Module 9 Axis Gyroscope Accelerometer Magnetic Field Sensor
- HC-SRF04 Proximity sensor
- GPS
- Voltage consumption sensor

## Actuators

- Acoustic alarm (Buzzer)
- Camera (in the future)
- DC motor

## Evaluation & PERFORMANCE

- Network technologies
- Embedded devices
- End-user point of view
- Battery Life (mAH) & latency (ms)

## Constraints

- All sensors are constantly sampled
- Bandwith and latency limitated by the capacity of LoraWAN
- Waterproof sensors
- Energy is a key factor in Safety Floater, we use solar panel in order to increase the battery life
- Power consumption reduced at minimum

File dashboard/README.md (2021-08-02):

# Web Dashboard

## Introduction
The **Web Dashboard** is one of the main component of our project. It is composed by two parts:

- the **server**, realized with **Node.js**
- the **frontend**, realized with **HTML, Bootstrap, Javascript, Vue.js**

It is directed to **coast guards** with the purpose of show them all the **violations** detected by the Sea Stations. Below we show a picture of all interactions at the Web Dashboard level:

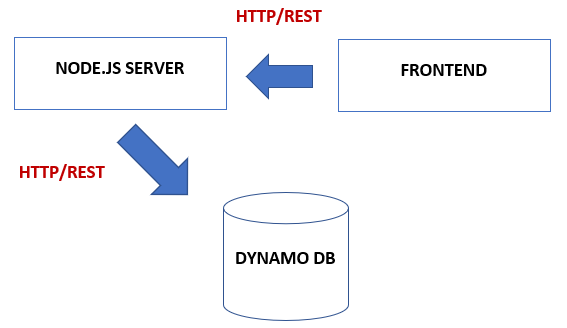
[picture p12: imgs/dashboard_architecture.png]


As we can see from the picture, the server interacts with a **DynamoBD** database, that acts as the **cloud on AWS** where we store data of each **violation** detected.

The login credentials are provided by the system admin to each user.

Finally, the frontend interacts with the server by using **HTTP/REST** calls.
 
## Overview
First, the user needs to **login** into the system by providing the login credentials:

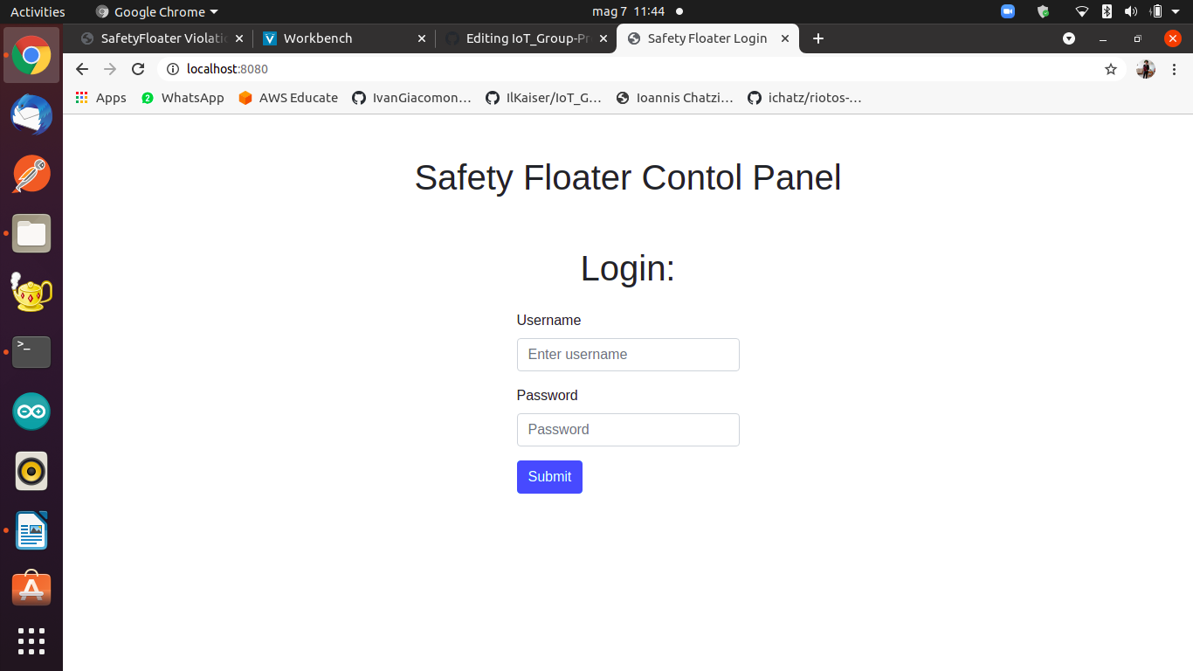
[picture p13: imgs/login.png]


After the login, he will be redirected to the **violations page**, where he can see all violations detected, from the most recent to the least recent. By clicking on **Logout**, he will be redirected to the login page. Below we can see a picture:

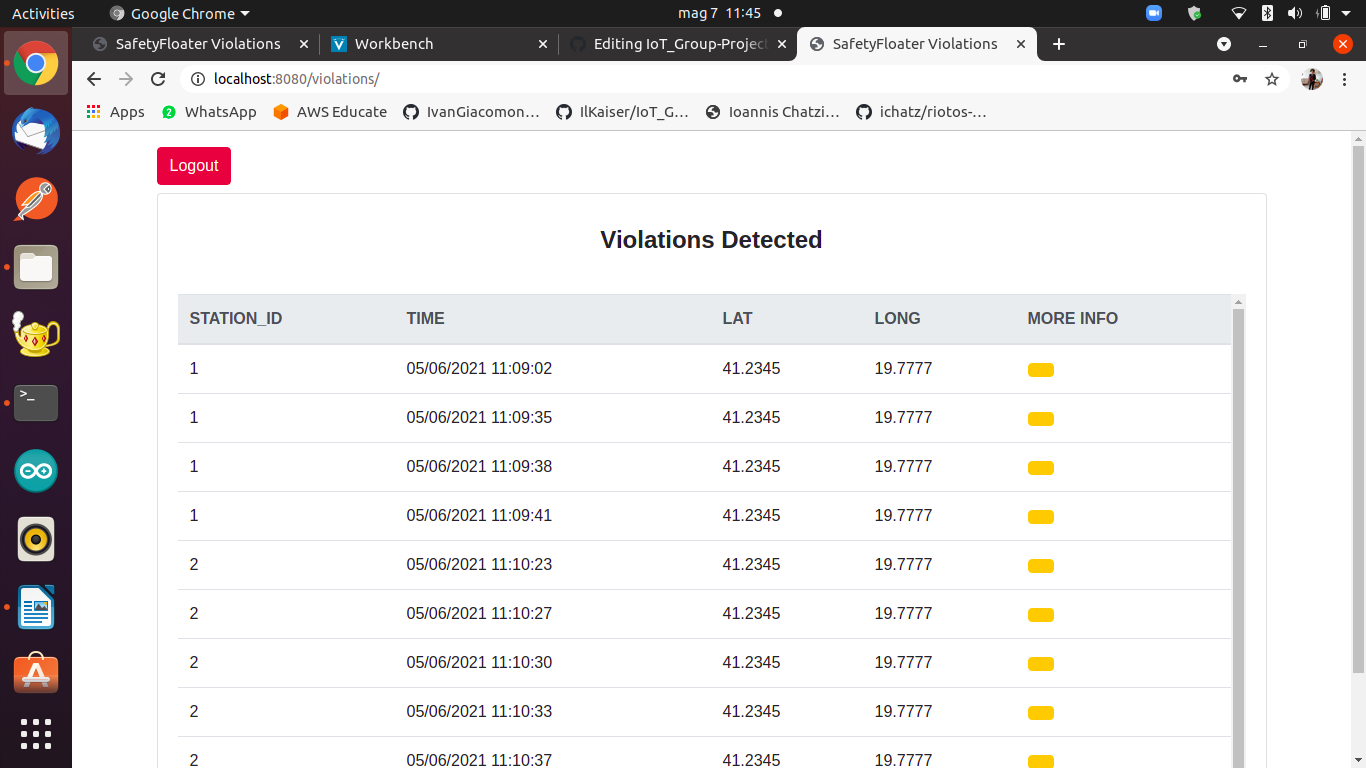
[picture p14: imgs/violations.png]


By clicking on the **More info** button of one violation, he will be redirected to a page where he can see the **picture of the boat** taken by the Raspberry pi Camera and a **map** with the marker pointing on the last known position of the Floater that correctly detected the violation. By clicking on **<-Back** he will be redirected to the violations page. Below we can see a couple of images:

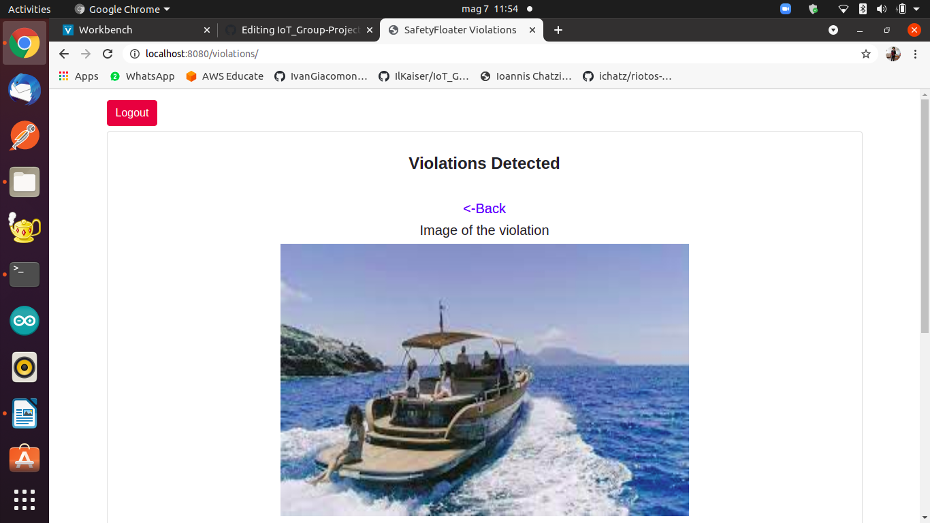
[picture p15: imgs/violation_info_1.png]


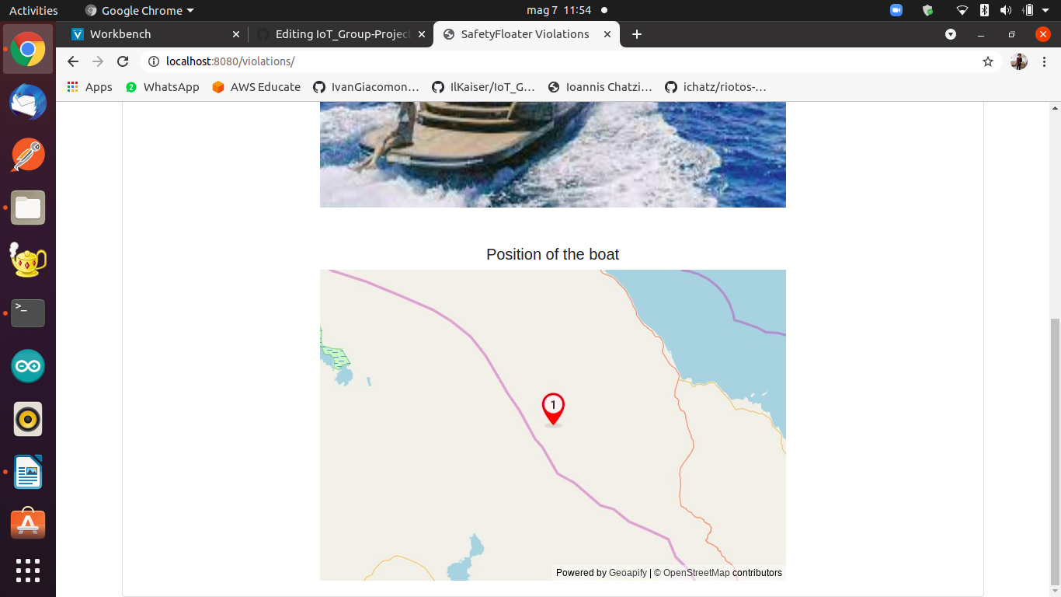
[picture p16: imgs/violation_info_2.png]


## Code
More info about the code can be found [here](https://github.com/IlKaiser/IoT_Group-Project/blob/main/dashboard/dashboard_code.md).

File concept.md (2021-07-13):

# Concept

## Introduction

Safety Floater is a project born to satisfy Blue Growth requirements for **coastal tourism**, in particular the monitoring and security of territory.
The goal is to detect the **illegal transit of boats** near by swimmers, in order to preserve the safe distance. This system allows the authorities to monitor coasts and tourists' welfare. At the same time, Safety Floater allows to achieve another goal in an indirect way: improve the water pollution near the coast.
So the system has two principal type of users: **tourists** and **coast guards**.

## Tourists

This is the first type of user the application is directed to. The main purpose is to **preserve the safety** of swimmers.
Below we propose two personas that represent this category.

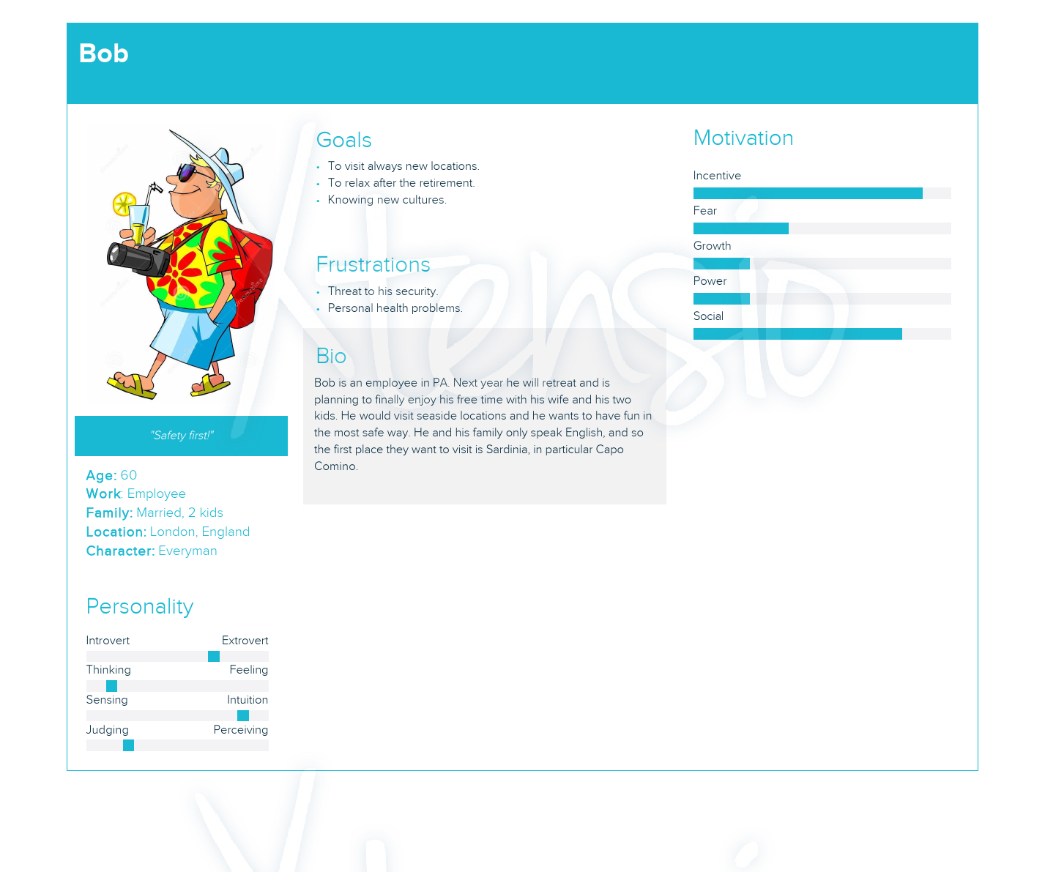
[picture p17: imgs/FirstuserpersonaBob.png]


As we can see from the above persona, Bob cares a lot about his family security, and with Safety Floater he feels more secure when his children go swim to the sea.
Also, he would like to enjoy his vacation, he wants to relax and he trusts the local authorities efficiency.

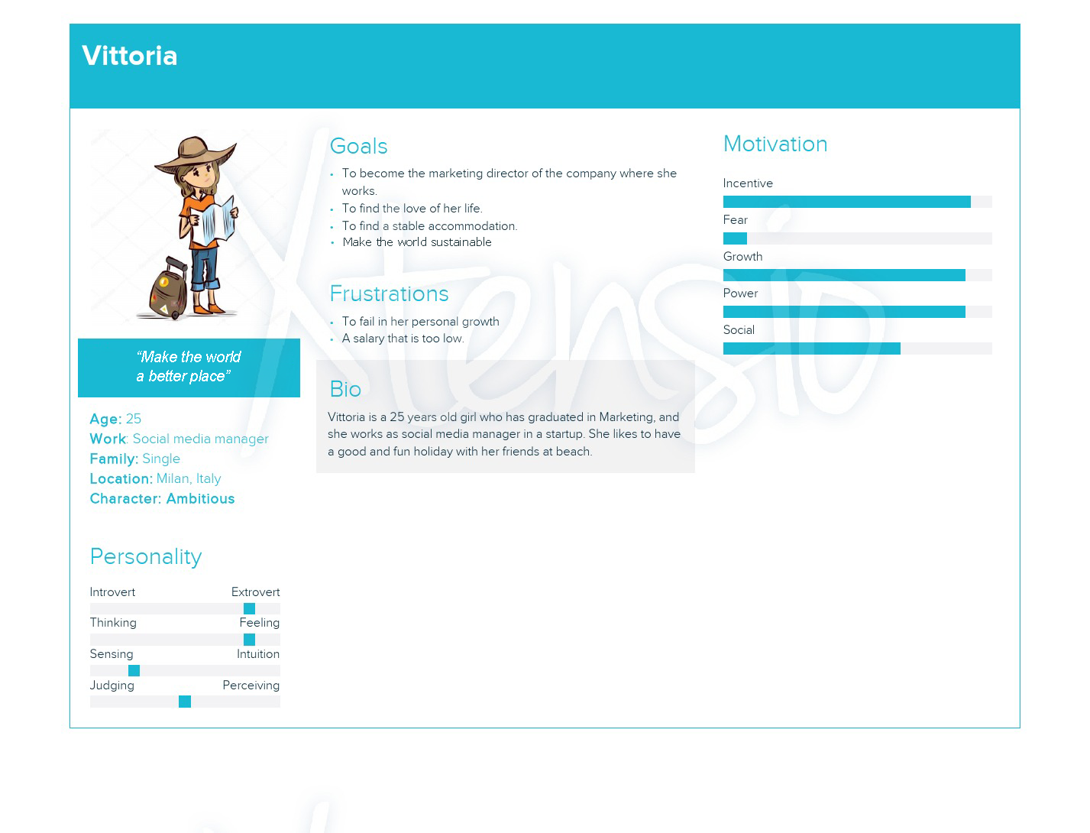
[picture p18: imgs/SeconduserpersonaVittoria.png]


As we can see from the above persona, Vittoria cares a lot about the environment, and with Safety Floater she is confident about the pollution of water caused by boats very close to the coast. So, she can have fun at sea without any worries, such as be hit by a boat while she is swimming.

## Coast guard

This is the second type of user the application is directed to. The main purposes are to **make boats respect the rules** in proximity of the beach, and also to allow an **immediate action of authorities**.
Below we propose one persona that represent this category.

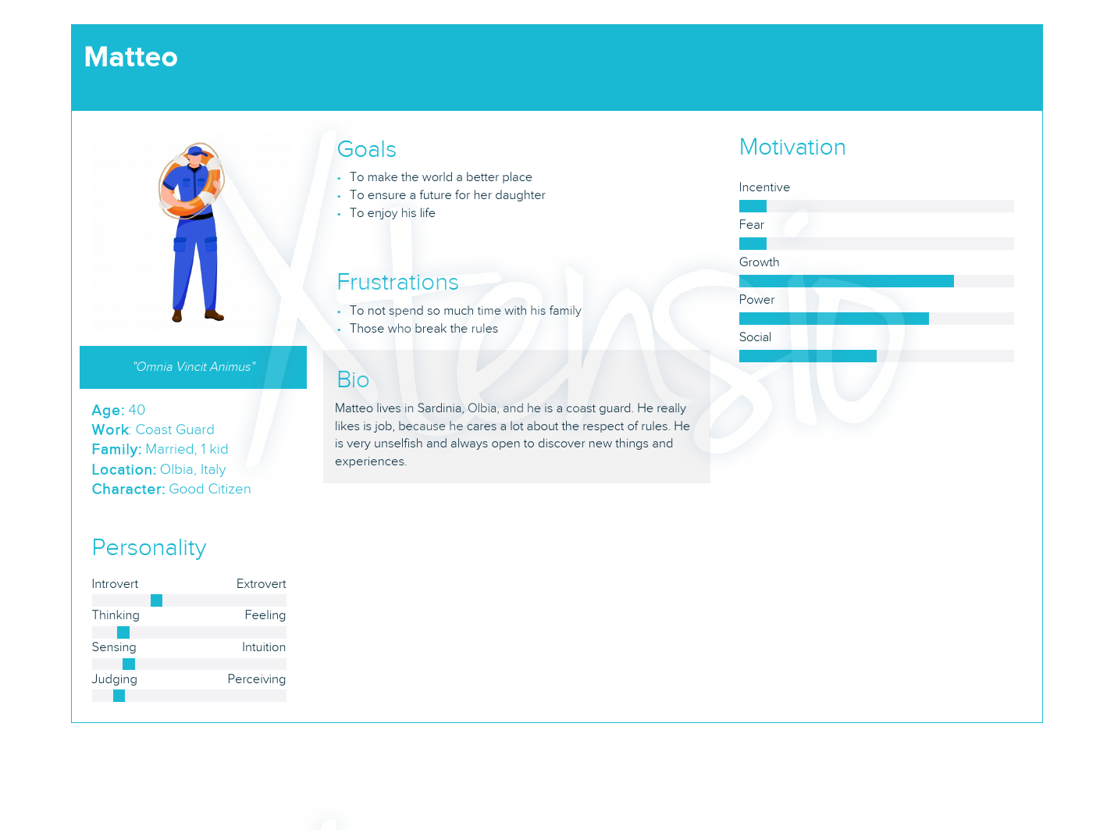
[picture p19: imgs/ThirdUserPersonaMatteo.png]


As we can see from the above persona, Matteo cares a lot about the safety of people, and with Safety Floater he is confident to do his job as best as he can.

## Use case

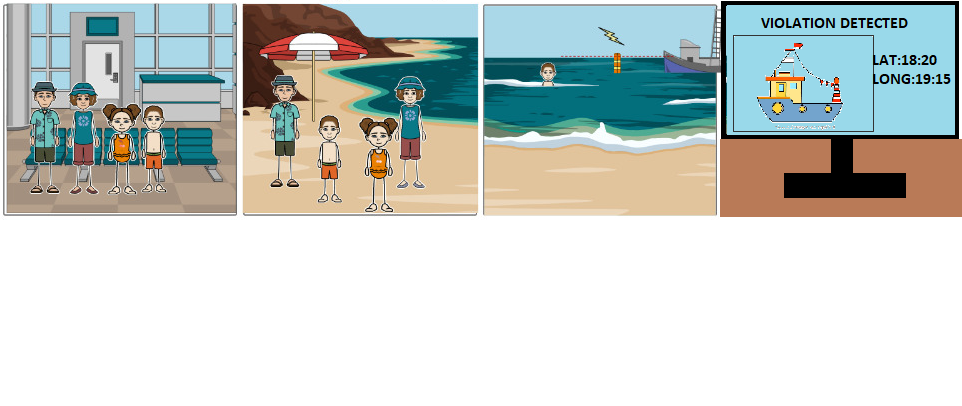
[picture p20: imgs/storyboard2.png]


Above we can see a typical use case: Bob wants to enjoy a holiday with his family, so they go to the airport in order to take a plain for Sardinia. When they arrive there, they are ready to enjoy some days at a beautiful beach. One day, however, while his son is swimming in the water nearby, Bob sees a boat approaching too close to safety line, but thanks to the Safety Floater system control he will be immediately alerted by by a sound notification, and in the meanwhile a picture of the boat will be available on the dashboard. 

## Previous version
The previous version of the document can be found in the [previous release](https://github.com/IlKaiser/IoT_Group-Project/releases/tag/2.0) of the project.

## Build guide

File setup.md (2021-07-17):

# Setup

## Devices

### STM32 Nucleo-64 F401RE board
You need to have available an **STM-32 Nucleo-64 F401RE board**, [here](https://www.st.com/en/evaluation-tools/nucleo-f401re.html) you can find info about it.

### Arduino Uno
You need to have available an **Arduino Uno board**, [here](https://store.arduino.cc/arduino-uno-rev3) you can find info about it.

### Raspberry pi 4
You need to have available an **Raspberry pi 4 board**, [here](https://www.raspberrypi.org/products/raspberry-pi-4-model-b/) you can find info about it.

## Arduino Uno setup

### Arduino IDE
You need to download the **Arduino IDE** from [here](https://www.arduino.cc/en/software).

### TinyGPSPlus library
You have to download the **TinyGPSPlus library** from [here](https://github.com/mikalhart/TinyGPSPlus/archive/refs/tags/v1.0.2b.zip), rename the folder in the zip as "TinyGPSPlus" and put it in the **libraries folder** of the Arduino folder.

## STM32 Nucleo-64 F401RE setup

### The RIOT operating system
We need to install the **RIOT operating system**, [here](https://github.com/RIOT-OS/Tutorials#tutorials-for-riot) you can find a tutorial for the installation.

## Raspberry pi 4 setup
For the **Raspberry pi 4** setup you can check [here](https://github.com/IlKaiser/IoT_Group-Project/blob/main/raspberry_code/Readme.md).

## Server setup

### Installing NodeJS and preparing the server
You need to install **NodeJS** in your operating system in order to have the web dashboard working correctly, [here](https://nodejs.org/en/) you can find details.
After this, you have to check if you have **npm** installed, otherwise you can install it from [here](https://www.npmjs.com/get-npm).
You also need to require the **.env** file, that has to placed in the dashboard directory. More info about the .env file will come later.

### Nodemon
After this, you can install **nodemon** (not mandatory), a very useful package to run our NodeJS server, with this command: **npm install -g nodemon** if you are on Windows, or **sudo npm install -g nodemon** if you are on Linux/Ubuntu.

## Data storage

### AWS, Iot-Core and DynamoDB
Then, you need so sign in in [AWS](https://aws.amazon.com/education/awseducate/), in order to get access to **Iot-Core** and **DynamoDB** services. Once you're on Iot-Core, you need to create a **thing** in order to get your **certificate**, **root certificate** and **private key**. Here you can find a [tutorial](https://docs.aws.amazon.com/iot/latest/developerguide/iot-moisture-create-thing.html). Then you need to add into the **.env** file **the access key id, the secret access key and the session token** provided by AWS, to be able to receive messages from the devices and to query the DynamoDB database. So at this point the .env should look like this:

```
AWS_ACCESS_KEY_ID=YOUR_AWS_ACCESS_KEY_ID
AWS_SECRET_ACCESS_KEY=YOUR_AWS_SECRET_ACCESS_KEY
AWS_SESSION_TOKEN=YOUR_AWS_SESSION_TOKEN
```

**NOTE!** The access key id, the secret access key and the session token provided by AWS expire after a while, so you have to manually re-set them in the .env file when this happens.

Then you need to **subscribe** to the **data/seastation/+** MQTT topic, where '+' stands for 'at least one character' from the syntax of regular expressions: in our case it will represent the **seastation id**. 

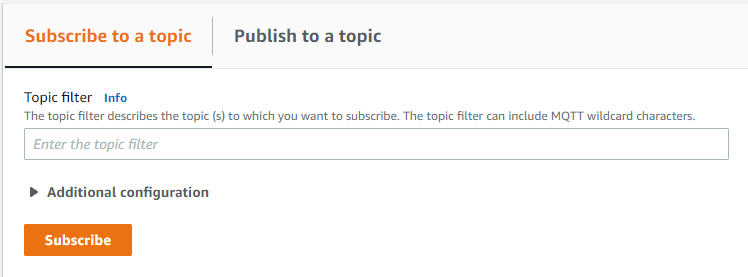
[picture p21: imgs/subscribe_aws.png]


Then by going in the Rules section you have to create a **rule** for violations, specifying as topic data/seastation/<seastation_id>, and as operation you need to choose "Insert a message into a DynamoDB table". Here you can find a [tutorial](https://docs.aws.amazon.com/iot/latest/developerguide/iot-ddb-rule.html).

**Violation rule**:

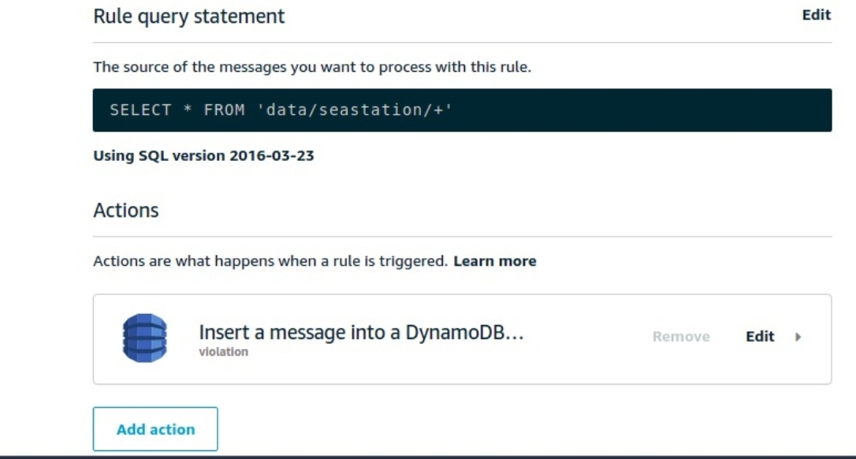
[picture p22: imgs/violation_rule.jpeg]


So it is clear that we will create a **DynamoDb table**: particularly, each entry of the table is made up of the **Unix timestamp** associated to the creation of that entry, the **seastation id** of the Sea Station that send the violation to AWS by MQTT, the **device_data**, which consists of the **seastation id**, the **violation id** of the violation detected, the **latitude** and **longitude** of the floater that send the indication of the violation to the Sea Station and the **url of the picture** taken by the Raspberry pi Camera. 

## Launching the application

- Download the repository from [here](https://github.com/IlKaiser/IoT_Group-Project/archive/refs/heads/main.zip), or clone it with **git clone https://github.com/IlKaiser/IoT_Group-Project.git**
- Open a terminal in the dashboard folder
- Launch **npm install**
- Launch the nodeJS server with **node index.js** or **nodemon** (if you installed it)
- Open the sensor.ino sketch in the arduino_code folder
- **Upload** the sketch
- Open another terminal in the nucleo_code folder of the project
- Launch the application by flashing the code into the STM-32 board with **make BOARD=nucleo-f401re flash term**
- For **Raspberry Pi 4** you can check all details [here](https://github.com/IlKaiser/IoT_Group-Project/blob/main/raspberry_code/Readme.md).

The server will be available at **http://localhost:8080/**.

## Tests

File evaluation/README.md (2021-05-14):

# Evaluation

## Introduction
As we have seen by the explanation of the [Nucleo code](https://github.com/IlKaiser/IoT_Group-Project/blob/main/nucleo_code/README.md), between our main purposes we can find a **power management system**: based on the value of **acceleration** along the **z-axis** that is constantly sampled from the **MPU9250** accelerometer, we have defined three **modalities** of our system:
- **high power consumption mode (high mode)**: the sea conditios are **good**, so our system needs to monitor the environment with an **high** frequence
- **normal power consumption mode (medium mode)**: the sea conditios are **stable**, so our system needs to monitor the environment with a **normal** frequence
- **low power consumption mode (low mode)**: the sea conditios are **not good**, so our system needs to monitor the environment with a **low** frequence

In order to have a better understanding of the power consumption of our system, we decided to use [Iot-lab](https://www.iot-lab.info/): in particular, you can check this [tutorial](https://iot-lab.github.io/docs/tools/consumption-monitoring/) in order to see more details.
First, we need to create a **monitoring profile**: 

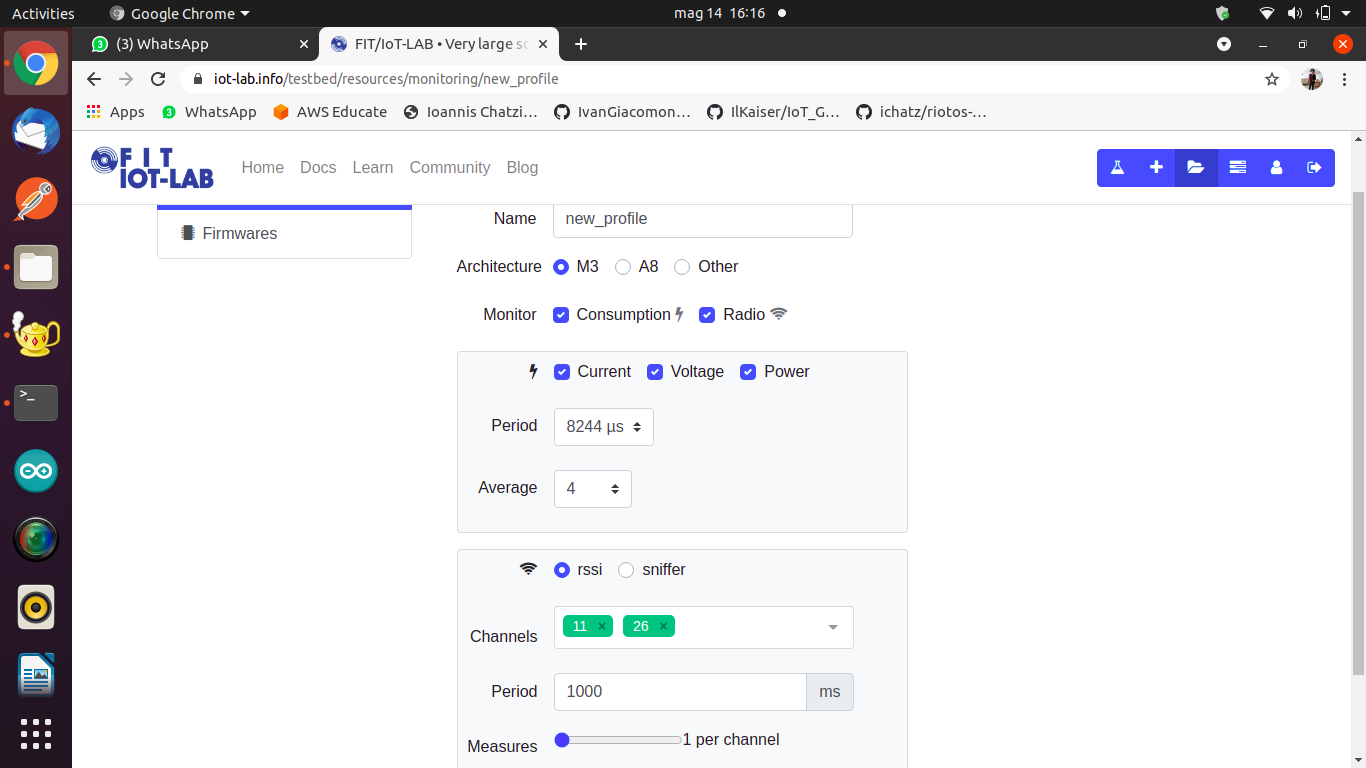
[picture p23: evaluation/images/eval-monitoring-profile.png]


The monitoring profile will allow us to measure consumption in terms of **power**. In particular, the metric used for the power is the **Watt (W)**. 

Then, in order to test our modalities separately, we need to create three different **experiments**. Below we show a picture of the experiment we used to test the high mode:

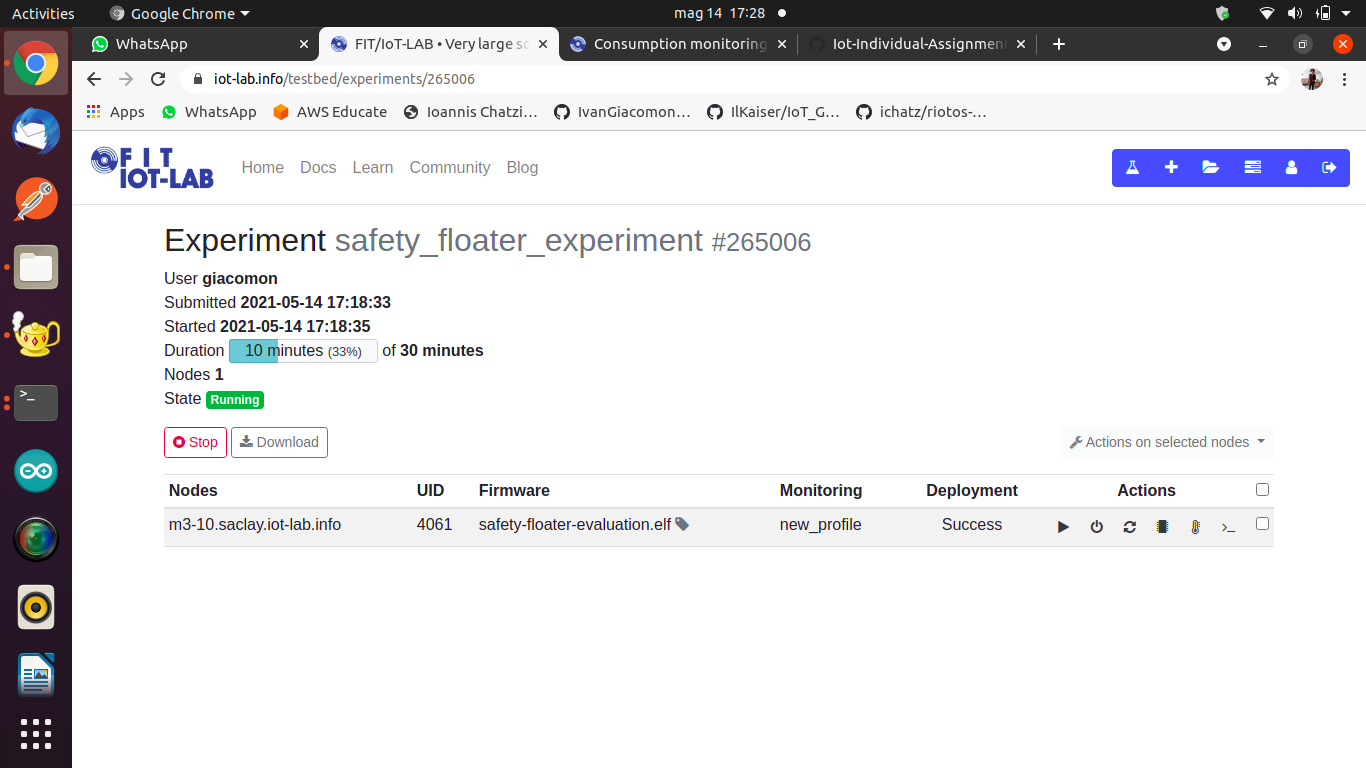
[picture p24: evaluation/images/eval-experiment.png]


As we can see, for the experiment we used the **Saclay** frontend, where we reserved **one M3-node** (**M3-10**) as a node for our **application**.

Finally, we tested all three modalities together by simulating the switch from one to another, so we created one last experiment, for a total of **4** experiments. All experiments lasted **30 minutes**.

## High mode
Below we show the results for the **high mode**, also with a zoomed view:

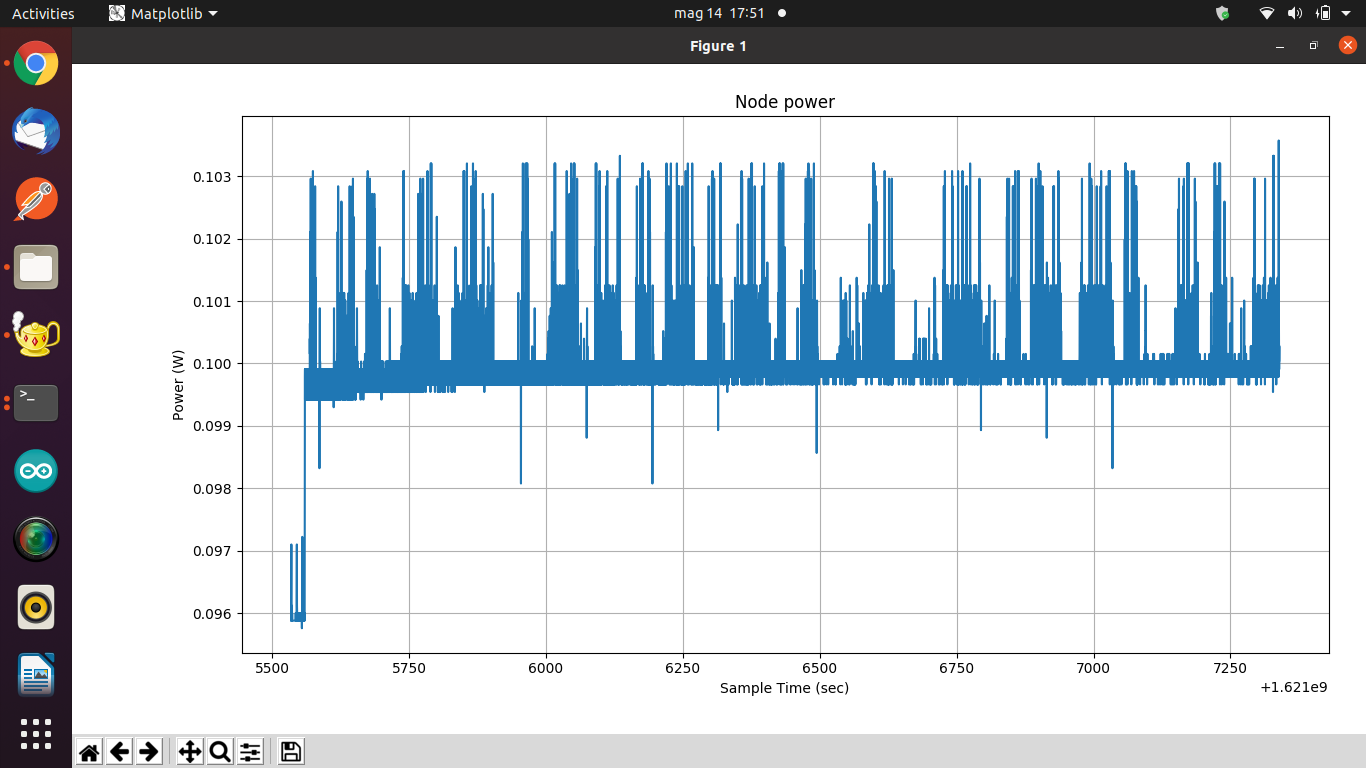
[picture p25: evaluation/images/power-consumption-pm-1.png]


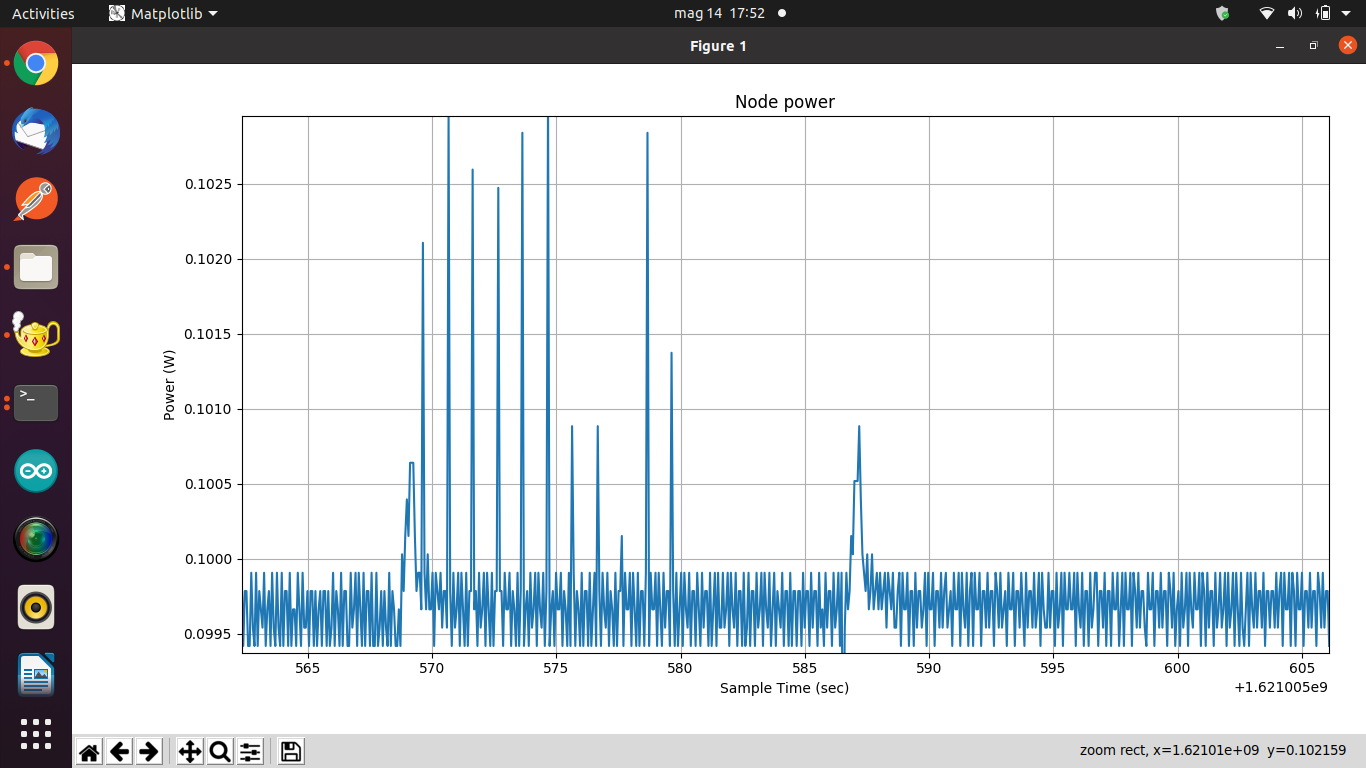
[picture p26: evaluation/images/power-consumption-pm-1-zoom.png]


As we can see, in a lot of points we have **peaks**, corresponding to the **sampling** of values. The main factor that affects this high power consumption is given by the simulated periodical sampling from the **MPU-9250**, that is in the order of **microseconds**. Obviously, as the number of wireless node increases, the performance of one of this nodes remain almost **similar**, because they are executing the same application code. At the beginning of the plot it's possible to see a little **noise** but the trend across the time it's stable: this noise can be explained by time occurred to setup and run the command from the application **shell**.

Below we also show a picture of the application running in the console in high mode:

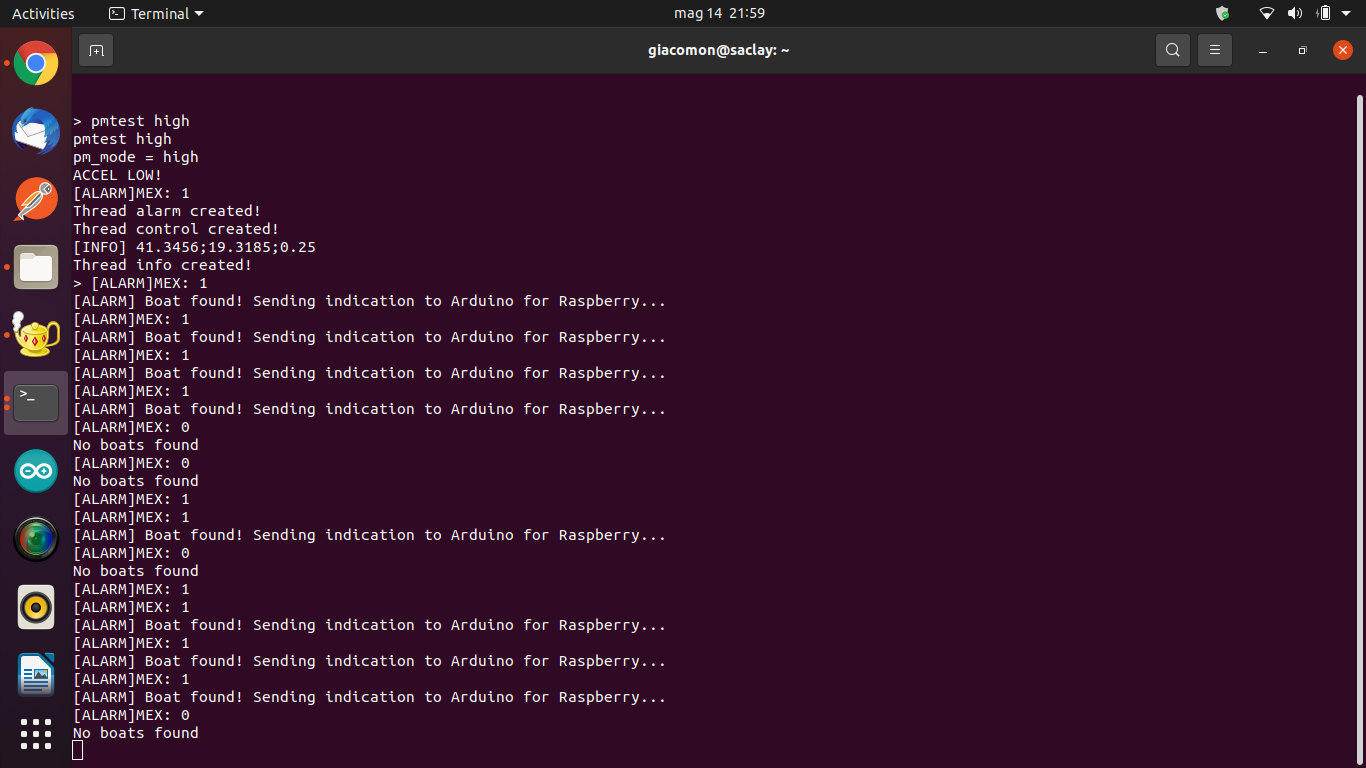
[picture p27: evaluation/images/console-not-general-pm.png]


## Medium mode
Below we show the results for the **medium mode**, also with a zoomed view:

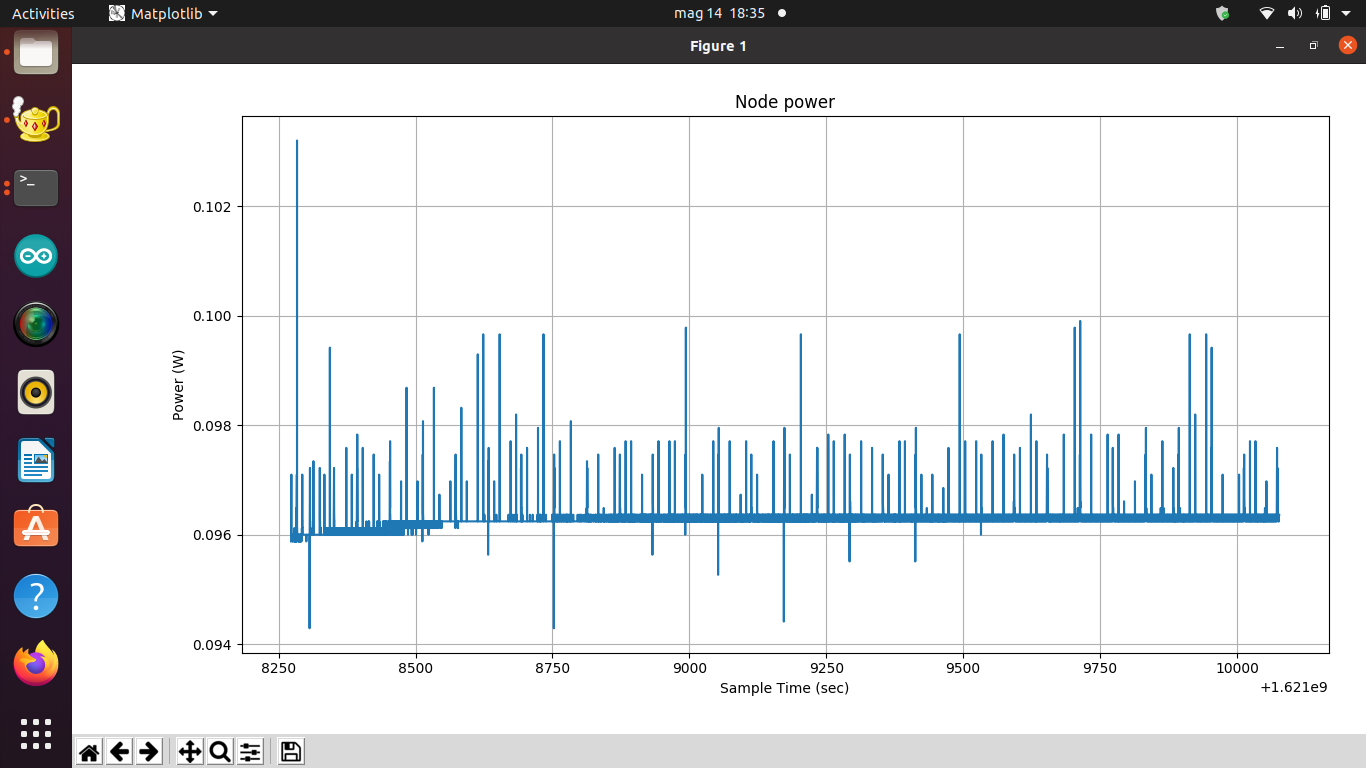
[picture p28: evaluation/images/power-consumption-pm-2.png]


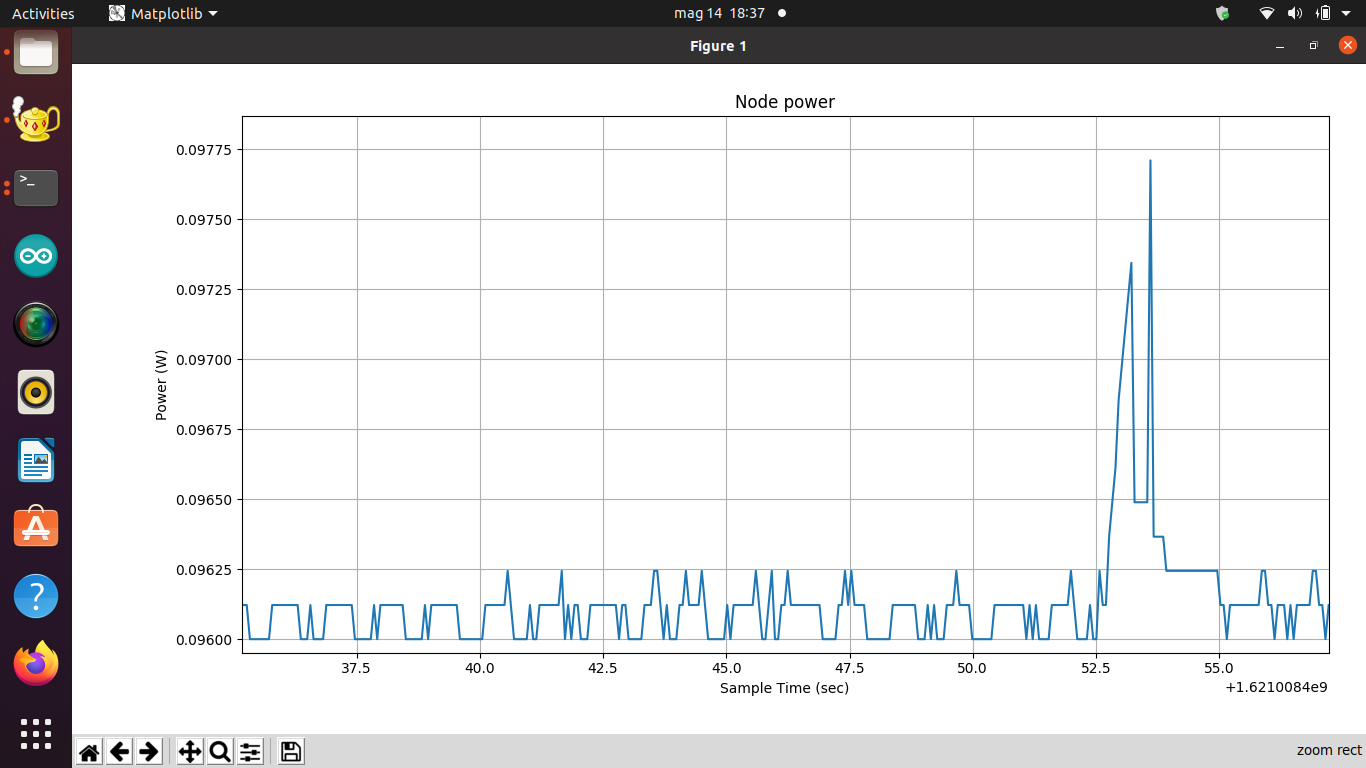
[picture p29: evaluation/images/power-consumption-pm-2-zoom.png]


As we can see, in some points we have **peaks**, corresponding to the **sampling** of values, but if we compare these plots with those of high mode above, for sure we have less peaks than there, because the sampling periods for all sensors are slightly **increased**: this leads to a **reduction** of the power consumption. All other observations done for high mode holds also for medium mode.

## Low mode
Below we show the results for the **low mode**, also with a zoomed view:

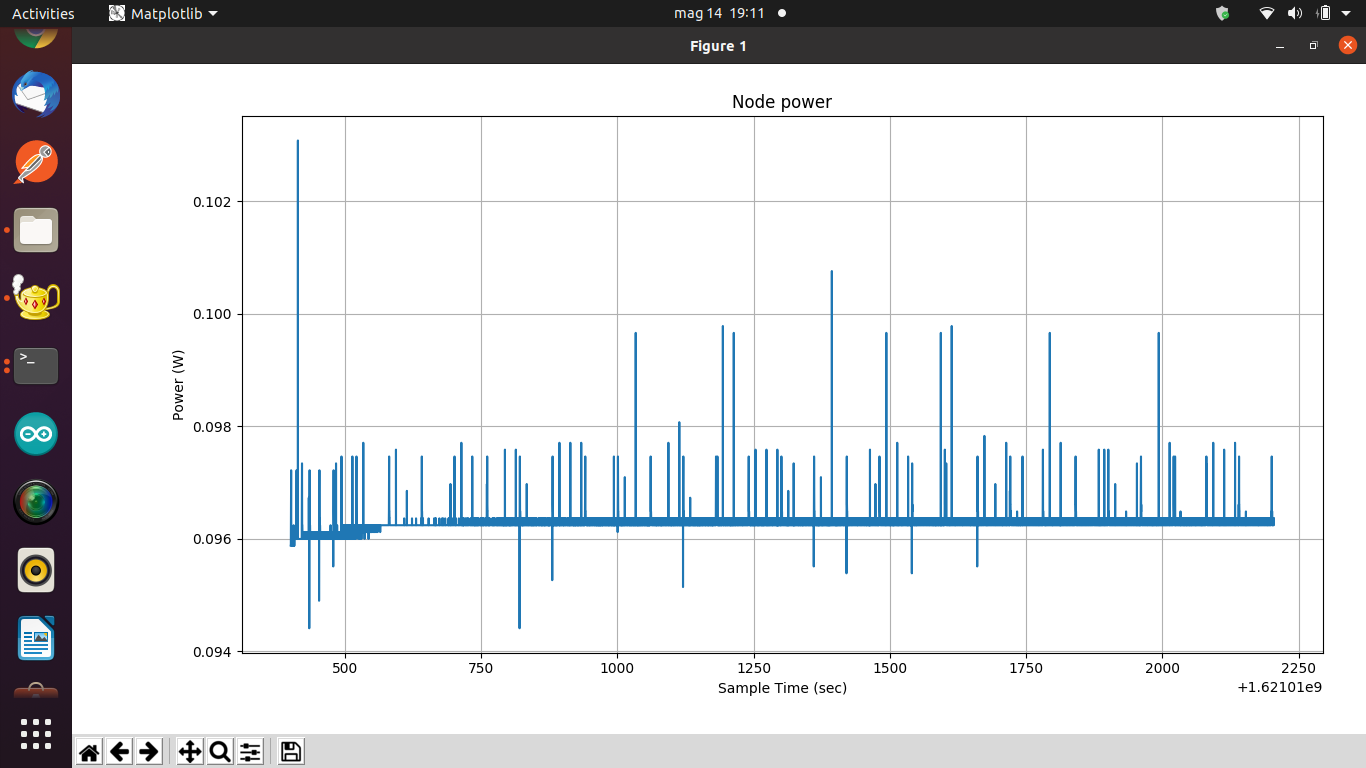
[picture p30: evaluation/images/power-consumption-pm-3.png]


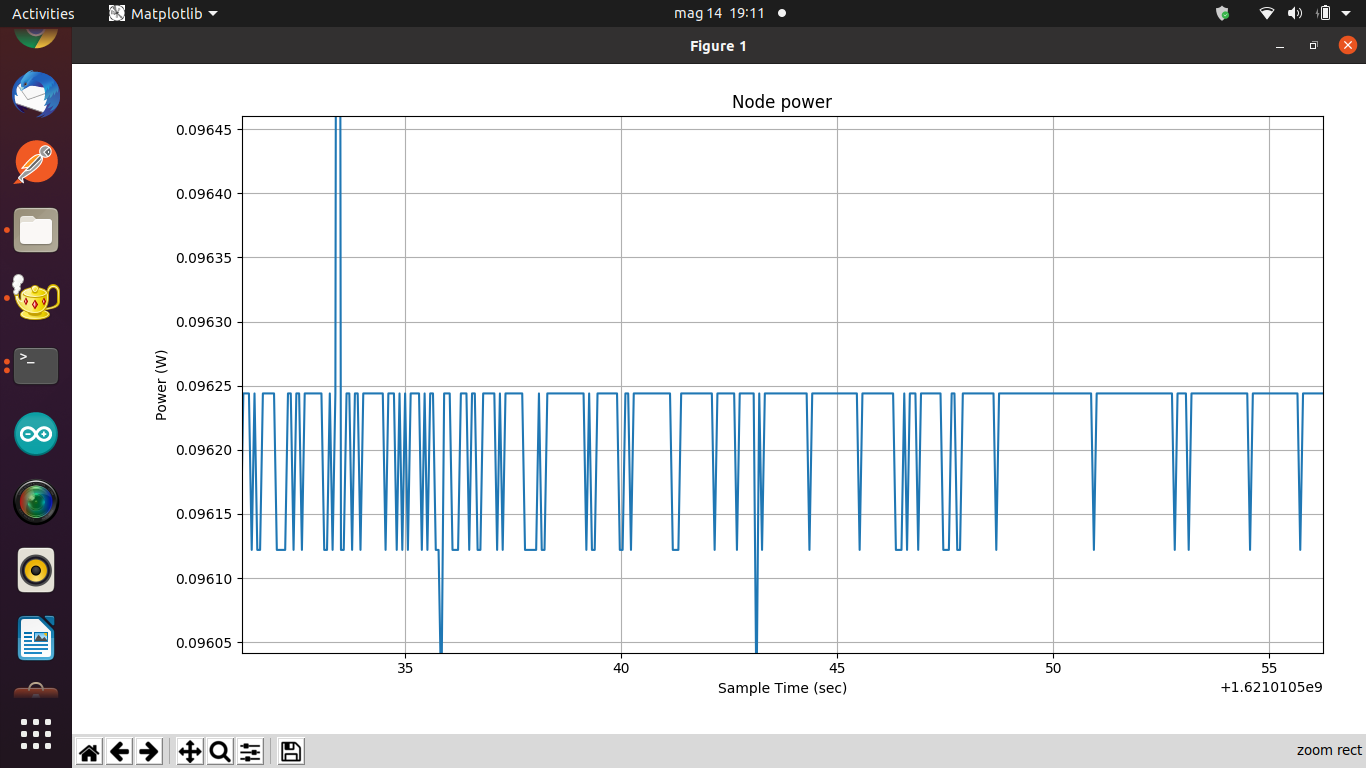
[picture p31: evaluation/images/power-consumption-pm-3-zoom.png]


As we can see, in some points we have **peaks**, corresponding to the **sampling** of values, but if we compare these plots with those of high mode and medium mode above, for sure we have less peaks than there, because the sampling periods for all sensors are, again, slightly **increased**: this leads to a further **reduction** of the power consumption. All other observations done for high mode and medium mode holds also for low mode.

## Genaral mode
Below we show the results for the **general mode**, where the switching occures after about **10 minutes**:

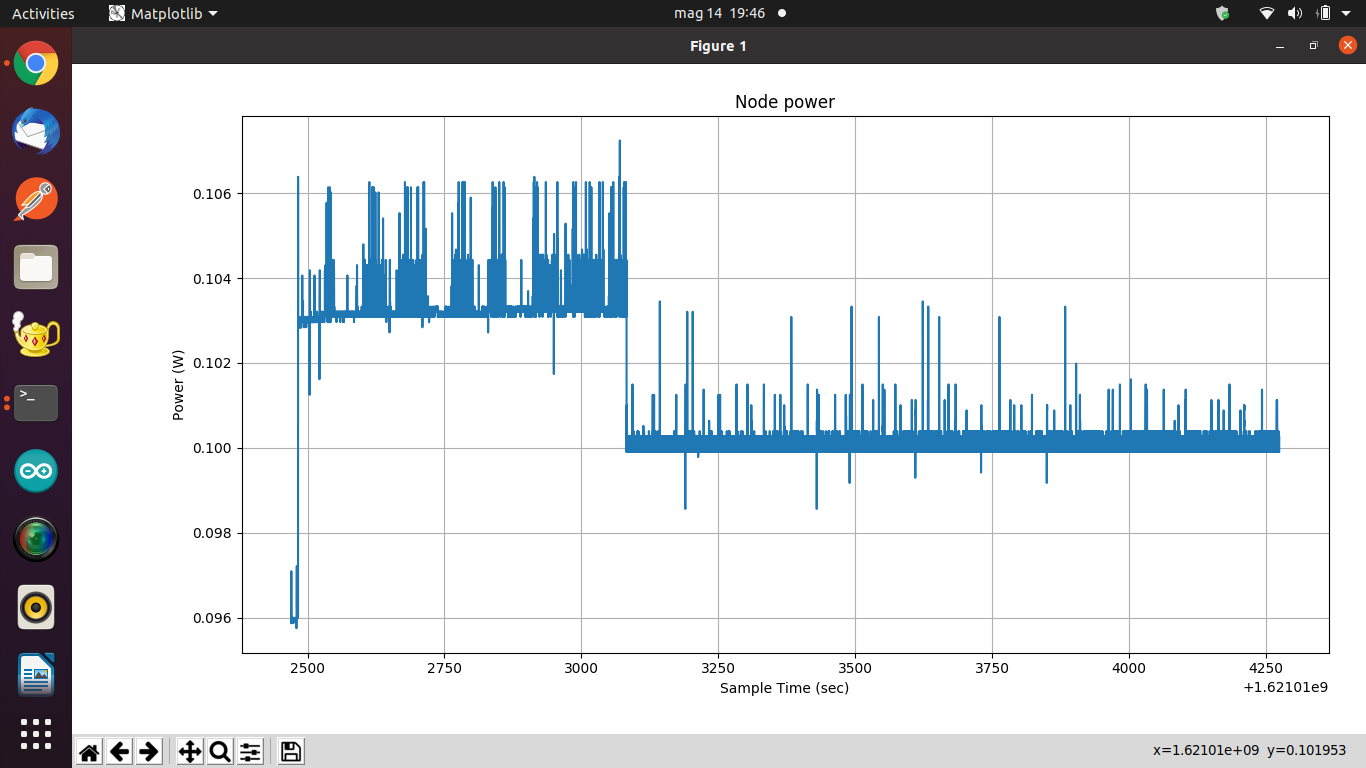
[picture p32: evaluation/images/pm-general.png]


In the first 10 minutes we can observe the trend of **high mode**, in the next 10 minutes the trend for **medium mode** and in the final 10 minutes the trend for **low mode**.

Below we also show a picture of the application running in the console in general mode at the moment of the switching from high mode to medium mode:



## Code
More info on the **Iotlab-m3 code** can be found [here](https://github.com/IlKaiser/IoT_Group-Project/blob/main/evaluation/iotlab-m3-code.md).

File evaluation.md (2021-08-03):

# Evaluation

## Network technologies
Given that Safety Floater will communicate with the Sea Station via LoraWAN, for our prototype we used a **Bluetooth module** in order to achieve an accurate measure of the **latency**. We have took into account the technological constraints of **LoraWan**, such as **throughput, latency and bandwith**.
<br><br>We also estimated the **latency** in the whole system by looking at: 
1. the total time needed to detect a **violation** on the **Nucleo board** for the activation of the **buzzer**
2. the total time needed to have the **boat picture** available on the Dashboard starting by the moment when the buzzer activates

To estimate these values we've used timestamps.

For the first measurement, we need to consider two delays:
   - the **I2C** delay for the communication between the Nucleo board and the Arduino board: about **0.001 seconds**
   - the delay to detect **false positives**: **1 second**

   So we have the following **estimates**:
   - Stm request of the current situation to the Arduino by I2C -> about **0.001 s**
   - Arduino response to the Stm by I2C -> about **0.001 s**
   - Delay to detect false positives -> **1 s**
   - Another request from the Stm of the current situation to the Arduino by I2C -> about **0.001 s**
   - Arduino response to the Stm by I2C -> about **0.001 s**

   **Total estimated time: 1.004 seconds.**

For the second measurement, we have the following **estimates**:
   - Stm request to the Arduino for the second violation check by I2C -> about **0.001 s**
   - Raspberry retrieves gps data from the Arduino by the Bluetooth module -> about **0.150 s**
   - Convolutional Neural Network evaluation -> about **3 s**
   - Sending of the picture url from the Raspberry to the AWS cloud by MQTT -> about **0.050 s**
   - HTTP/REST request from the NodeJS server to the cloud to retrieve the picture url in order to show the picture on the Dashboard -> about **0.050 s**

   **Total estimated time: 3.251 seconds.**
   
**Final estimated time: (1.004 seconds + 3.251 seconds)  = 4.255 seconds.**

For the second measurement, we've considered also a **LoraWAN communication** instead of a Bluetooth communication, so the second part of the estimation changed. The amount of bytes that we've sent from the Safety Floater to the Sea Station is **(Identifier of the floater, latitude and longitude)**, then we send **12 bytes** using LoraWAN. 
   
   - Stm request to the Arduino for the second violation check by I2C -> about **0.001 s**
   - Raspberry retrieves gps data from the Arduino by the LoraWAN module ( [Source](http://alessandroblason.it/2017/07/12/ttn-la-politica-accesso-equo/)) -> about **1.051 s**
   - Convolutional Neural Network evaluation -> about **3.000 s**
   - Sending of the picture url from the Raspberry to the AWS cloud by MQTT -> about **0.050 s**
   - HTTP/REST request from the NodeJS server to the cloud to retrieve the picture url in order to show the picture on the Dashboard -> about **0.050 s**

**Final estimated time: (1.004 seconds + 4.152 seconds) = 5.156 seconds.**

## Embedded devices

### IOT-LAB ESTIMATION
We measured the **power consumption** and **correction accuracy** of the stepper motor. The power consumption has been monitored on [Iot-lab](https://www.iot-lab.info/), on the basis of the **power management system** that we have defined [here](https://github.com/IlKaiser/IoT_Group-Project/blob/main/2nd_delivery.md#presentation-of-technical-work). Our system will be able to adapt itself with respect to the **acceleration** measured from the **MPU-9250** accelerometer along the **z-axis**, by switching in three possible modalities:

- **high mode**: high power consumption mode means that **the sea is calm** and it's possible to associate this power mode to the **white flag**
- **medium mode**: medium power consumption mode means that **the sea is in a intermediate status** and it's possible to associate this power mode to the **yellow flag**
- **low mode**: low power consumption mode means that **the sea is rough** and it's possible to associate this power mode to the **red flag**

During these experiments we kept the system running for **30 minutes** each, and we simulated the passive situation on which there wasn't a boat that crosses the safety line. 

Below we report the results obtained for each mode, also with a zoomed view, and also a final picture that shows the switching between modes, in particular from the high mode to the medium mode first, and from the medium mode to the low mode later:

### High mode





### Medium mode





### Low mode





### General mode (with switching)



More details on the evaluation of the power consumption can be found [here](https://github.com/IlKaiser/IoT_Group-Project/blob/main/evaluation/README.md).

### SIMULATED ENVIRONMENT WITH THE PROTOTYPE 

For the third deliver we've realized a **prototype** an we decided to measure the power consumption. We kept running the floater for **60 minutes** for each **power consumption mode** and for the power supply we used a powerbank and we've simulated a boat that crossed the safety line every **5 minutes**.

This is the setup:



Below we can see results for each power consumption mode:

**HIGH MODE**

Voltage: 5 V <br>
Current Consumption: 153 mAh <br>
**Power Consumption: 7 hours 50 minutes using a 9V 1200 mAh battery without considering solar panel**

**MEDIUM MODE**

Voltage: 5 V <br>
Current Consumption: 138,65 mAh <br>
**Power Consumption: 8 hours 45 minutes using a 9V 1200 mAh battery without considering solar panel**

**LOW MODE**

Voltage: 5 V <br>
Current Consumption: 137,5 mAh <br>
**Power Consumption: 8 hours 55 minutes using a 9V 1200 mAh battery without considering solar panel**

## Detection accuracy with CNN
We measured the accuracy and performances of the **Convolutional Neural Network** we trained for boat recognition. The dataset used is **ARGOS**, and the results are in the picture below:



## End-user point of view
From an end-user point of view the response time is conditioned by **LoraWAN**, by the **bandwith of the channel linking the Sea Station to the cloud**, and by the type of **protocol** used (**MQTT**). From a quantitative point of view, we will use **timestamps** at the generation of the packet and one at the receiving of the packet.  

## Previous version
The previous version of the document can be found in the [previous release](https://github.com/IlKaiser/IoT_Group-Project/releases/tag/2.0) of the project.

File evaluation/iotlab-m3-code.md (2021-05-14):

# Iotlab-m3 code

## Shell initialization
The application starts by initializing a **message queue** for the thread running the shell, and then runs the shell, that will be useful for launching the application on the M3-node in the diffent modes:

```c
msg_init_queue(_main_msg_queue, MAIN_QUEUE_SIZE);

char line_buf[SHELL_DEFAULT_BUFSIZE];
shell_run(shell_commands, line_buf, SHELL_DEFAULT_BUFSIZE);
```

In order to do this, we need to include these **modules** in the [Makefile](https://github.com/IlKaiser/IoT_Group-Project/blob/main/evaluation/Makefile):

```c
USEMODULE += shell
USEMODULE += shell_commands
USEMODULE += ps
```

Also, we need to include these **headers** in the [main.c](https://github.com/IlKaiser/IoT_Group-Project/blob/main/evaluation/main.c):

```c
#include "shell.h"
#include "msg.h"
```

Then we need to define the **message queue** together with its **size** in the [main.c](https://github.com/IlKaiser/IoT_Group-Project/blob/main/evaluation/main.c):

```c
#define MAIN_QUEUE_SIZE     (8)
static msg_t _main_msg_queue[MAIN_QUEUE_SIZE];
```

Then, we need to define the **shell_commands** in the [main.c](https://github.com/IlKaiser/IoT_Group-Project/blob/main/evaluation/main.c):

```c
static const shell_command_t shell_commands[] = {
    { "pmtest", "starts the application with a certain power management level", cmd_handler},
    { NULL, NULL, NULL }
};
```

## cmd_handler
As we can see, we only have one customized command, that is **pmtest**, which is responsible of starting the application by invoking the *cmd_handler* function, that we report below:

```c
int cmd_handler(int argc, char **argv){
    (void)argc;
    (void)argv;
    
    char* mode = argv[1];
    
    // Saving pm mode into a global variable
    pm_mode = mode;
    
    printf("pm_mode = %s\n",pm_mode);
    
    if(strcmp(mode, POWER_MANAGEMENT_HIGH) != 0 && strcmp(mode, POWER_MANAGEMENT_MEDIUM) != 0 &&
       strcmp(mode, POWER_MANAGEMENT_LOW) != 0 && strcmp(mode, POWER_MANAGEMENT_GENERAL) != 0){
       
       printf("Please insert %s or %s or %s or %s\n", POWER_MANAGEMENT_HIGH, POWER_MANAGEMENT_MEDIUM, POWER_MANAGEMENT_LOW, POWER_MANAGEMENT_GENERAL);
       
       exit(EXIT_FAILURE);  
    }
    
    if(strcmp(mode, POWER_MANAGEMENT_GENERAL) != 0){
	    fixedPowerManagement(mode);   	
	}
	
	else{
	    printf("Power management: general mode inserted!\n");
	    
	    thread_create(stackThreadTimer,sizeof(stackThreadTimer),THREAD_PRIORITY_MAIN-1,0,threadTimer,NULL,"Thread Timer");
		printf("Thread timer created! \n");
	}
	
	thread_create(stackThreadAlarm,sizeof(stackThreadAlarm),THREAD_PRIORITY_MAIN-1,0,threadAlarm,NULL,"Thread Alarm detection");
	printf("Thread alarm created! \n");
	
	thread_create(stackThreadControl,sizeof(stackThreadControl),THREAD_PRIORITY_MAIN-1,0,threadControl,NULL,"Thread Control");
	printf("Thread control created! \n");
	
	thread_create(stackThreadInfo,sizeof(stackThreadInfo),THREAD_PRIORITY_MAIN-1,0,threadInfo,NULL,"Thread Info ");
	printf("Thread info created! \n");
		
    return 0;
}
```

### Power modes

The cmd_handler takes as input the **number of arguments** of the program and the **effective arguments**. We only have one argument, that is the **mode** that will be assigned to the instance of the application. As discussed [here](https://github.com/IlKaiser/IoT_Group-Project/blob/main/evaluation/README.md), there will be **4** different modes:
- **high mode**
- **medium mode**
- **low mode**
- **general mode**

We need to define the **power modes macros** in the [main.c](https://github.com/IlKaiser/IoT_Group-Project/blob/main/evaluation/main.c):

```c
#define POWER_MANAGEMENT_HIGH           "high"
#define POWER_MANAGEMENT_MEDIUM         "medium"
#define POWER_MANAGEMENT_LOW            "low"
#define POWER_MANAGEMENT_GENERAL        "general"
```

After validating the mode, the application checks whether we are in general mode or not:
- if we are in general mode, the application creates a **timer thread**
- otherwise, the application simply fixes the sampling delays based on the inserted mode, with the help of the *fixedPowerManagement* function

In order to create the thread we need to include this **header** in the [main.c](https://github.com/IlKaiser/IoT_Group-Project/blob/main/evaluation/main.c):

```c
#include "thread.h"
```

We also need to define a **stack** for the thread in the [main.c](https://github.com/IlKaiser/IoT_Group-Project/blob/main/evaluation/main.c):

```c
static char stackThreadTimer[THREAD_STACKSIZE_DEFAULT];
```

## Timer thread
Below I report the *threadTimer* function:

```c
static void* threadTimer(void* arg){
	(void)arg;
	
	// Start measuring time
	time_t begin, end;
	time(&begin);
    
	char* modeIdentifier = POWER_MANAGEMENT_HIGH;
	
	printf("[TIMER] Now in mode %s\n",modeIdentifier);
	
	while(1){
	  	// Stop measuring time and calculate the elapsed time
		time(&end);
		time_t elapsed = end - begin;
		
		//printf("Elapsed time: %ld seconds.\n", elapsed);
		
		if(elapsed >= CONTROL_TIME_THRESHOLD){
				
			long int el = elapsed;
				
			printf("Elapsed time: %ld seconds.\n", el);
			runtimePowerManagement(&modeIdentifier);
			
			printf("[TIMER] Now in mode %s\n",modeIdentifier);
		    
			// Restart measuring time
			time(&begin);
		}
	    
	    xtimer_usleep(DELAY_TIMER);
	}
	
	return NULL;
}
```

This thread continuosly evaluates the **elapsed time**, in particular every **DELAY_TIMER** seconds and, if the elapsed time exceeds the **CONTROL_TIME_THRESHOLD**, then the **mode** is automatically changed with a predefined logic that we can find in the *runtimePowerManagement* function, and the timer is restarted.

In order to use the timer, we need to include this **header** in the [main.c](https://github.com/IlKaiser/IoT_Group-Project/blob/main/evaluation/main.c):

```c
#include <time.h>
```

We need to define the **CONTROL_TIME_THRESHOLD** in the [main.c](https://github.com/IlKaiser/IoT_Group-Project/blob/main/evaluation/main.c) as follows:

```c
#define CONTROL_TIME_THRESHOLD         600
```

We need to define the **delay period constant** for the timer thread as follows in the [main.c](https://github.com/IlKaiser/IoT_Group-Project/blob/main/evaluation/main.c):

```c
#define DELAY_TIMER      500
```

In order to do a periodical check of the elapsed time, we need to include the **xtimer module** in the [Makefile](https://github.com/IlKaiser/IoT_Group-Project/blob/main/evaluation/Makefile):

```c
USEMODULE += xtimer
```

Also, we need to include this **header** in the [main.c](https://github.com/IlKaiser/IoT_Group-Project/blob/main/evaluation/main.c):

```c
#include "xtimer.h"
```

### runtimePowerManagement function

```c
void runtimePowerManagement(char** modeIdentifier){
    printf("Switching from mode %s to mode ",*modeIdentifier);
    
    if(strcmp(*modeIdentifier, POWER_MANAGEMENT_HIGH) == 0){
		printf("%s\n",POWER_MANAGEMENT_MEDIUM);
		
		*modeIdentifier = POWER_MANAGEMENT_MEDIUM;
		
		delay_alarm = DELAY_ALARM_MEDIUM;
		delay_control = DELAY_CONTROL_MEDIUM;
		delay_info = DELAY_INFO_MEDIUM;	
	}
	
	else if(strcmp(*modeIdentifier, POWER_MANAGEMENT_MEDIUM) == 0){
		printf("%s\n",POWER_MANAGEMENT_LOW);
		
		*modeIdentifier = POWER_MANAGEMENT_LOW;
		
		delay_alarm = DELAY_ALARM_HIGH;
		delay_control = DELAY_CONTROL_HIGH;
		delay_info = DELAY_INFO_HIGH;	
	}
	
	else if(strcmp(*modeIdentifier, POWER_MANAGEMENT_LOW) == 0){
	    printf("%s\n",POWER_MANAGEMENT_HIGH);
	    
	    *modeIdentifier = POWER_MANAGEMENT_HIGH;
		
		delay_alarm = DELAY_ALARM_BASE;
		delay_control = DELAY_CONTROL_BASE;
		delay_info = DELAY_INFO_BASE;	
	}
}
```

The *runtimePowerManagement* function takes as input the **address of the current mode** that our application is running, and based on that, change the mode in **circular way** by setting the corresponding **sampling delays**.

We need to define the **sampling delays** for each mode in the [main.c](https://github.com/IlKaiser/IoT_Group-Project/blob/main/evaluation/main.c):

**High mode delays**
```c
#define DELAY_INFO_BASE 30
#define DELAY_ALARM_BASE 1
#define DELAY_CONTROL_BASE 100
```

**Medium mode delays**
```c
#define DELAY_INFO_MEDIUM 50
#define DELAY_ALARM_MEDIUM 10
#define DELAY_CONTROL_MEDIUM 10000000
```

**Low mode delays**
```c
#define DELAY_INFO_HIGH 70
#define DELAY_ALARM_HIGH 20
#define DELAY_CONTROL_HIGH 60000000
```

## fixedPowerManagement function

```c
void fixedPowerManagement(char* mode){
    if(strcmp(mode, POWER_MANAGEMENT_HIGH) == 0){
		printf("ACCEL LOW!\n");
		    
		delay_alarm = DELAY_ALARM_BASE;
		delay_control = DELAY_CONTROL_BASE;
		delay_info = DELAY_INFO_BASE;	
	}
    
    else if(strcmp(mode, POWER_MANAGEMENT_MEDIUM) == 0){
		printf("ACCEL MEDIUM!\n");
		    
		delay_alarm = DELAY_ALARM_MEDIUM;
		delay_control = DELAY_CONTROL_MEDIUM;
		delay_info = DELAY_INFO_MEDIUM;	
	}
		
	else if(strcmp(mode, POWER_MANAGEMENT_LOW) == 0){
		printf("ACCEL HIGH!\n");
		    
		delay_alarm = DELAY_ALARM_HIGH;
		delay_control = DELAY_CONTROL_HIGH;
		delay_info = DELAY_INFO_HIGH;	
	}
}
```

The *fixedPowerManagement* function takes as input the mode inserted by the user, and sets as **sampling delays** the delays corresponding to that mode.

## Sampling threads

Finally, the handler initializes the **sampling threads**, the same as those seen in the [real application](https://github.com/IlKaiser/IoT_Group-Project/blob/main/nucleo_code/README.md), that will simulate the sampling of data from **sensors**. In order to create these threads, we need to define their **stacks** in the [main.c](https://github.com/IlKaiser/IoT_Group-Project/blob/main/evaluation/main.c):

```c
static char stackThreadAlarm[THREAD_STACKSIZE_DEFAULT];
static char stackThreadInfo[THREAD_STACKSIZE_DEFAULT];
static char stackThreadControl[THREAD_STACKSIZE_DEFAULT];
```

### Alarm thread

```c
static void* threadAlarm(void* arg)
{
    (void)arg;
    
    srand(time(NULL));
	
	int cont=0;
	while(1)
	{	
		int alarm_response = rand() % 2;
		
		printf("[ALARM]MEX: %d \n",alarm_response);
		
		if(alarm_response == 1)
			cont++;
		else
			cont=0;

		if(cont>=ALARM_THRESHOLD){
			printf("[ALARM] Boat found! Sending indication to Arduino for Raspberry...\n");
		}
		if(cont==0){
			printf("No boats found \n");
		}

		xtimer_sleep(delay_alarm);
	
	}
	
	return NULL;
}
```

The **alarm thread** is responsible for the simulation of **boat detections**. The detection is completely random, based on a **boolean random variable** continuosly generated every **delay_alarm** seconds, and if '1' is extracted **ALARM_THRESHOLD** or more time in a row, we assume that there was a **violation**, otherwise the counter is restarted.

We need to define the **ALARM_THRESHOLD** and the **delay_alarm** in the [main.c](https://github.com/IlKaiser/IoT_Group-Project/blob/main/evaluation/main.c):

```c
#define ALARM_THRESHOLD 2

int delay_alarm = DELAY_ALARM_BASE;
```

Notice that the delay_info is setted to the delay corresponding to the **high mode**, and the same holds for the other sampling delays that we will see later.

### Control thread

```c
static void* threadControl(void* arg)
{
	(void)arg;
	
	srand(time(NULL));

	//sample values for magnetic field detected by the compass and accelerometer
    short x_compass, x_start_compass;
	
	getControlData(&x_compass, &x_start_compass);
	
	//get control data correction degree will be saved into buffer with sintax -360/360 as char*
	while(1)
	{
		
		//get control data
	    getControlData(&x_compass, &x_start_compass);
	    
	    //printf("[CONTROL] x_start_compass = %hd\n",x_start_compass);
	    //printf("[CONTROL] x_compass = %hd\n",x_compass);
				
		// Proximity sensor correction
		proximitySensorCorrection(x_start_compass, x_compass);
		
		xtimer_usleep(delay_control);
	}
	
	return NULL;
}
```

The **control thread** is responsible for the simulation of **proximity sensor correction**. Samplings from the the **MPU-9250** are simulated through the *getControlData* function:

```c
void getControlData(short* x_compass, short* x_start_compass){
    
    if(!first_read_compass_done){
	    *x_start_compass = rand() % 50;
		*x_compass = *x_start_compass;
		
		first_read_compass_done = 1;
	}
	
	else{
		
		int lower = *x_start_compass - 2;
		int upper = *x_start_compass + 2;
		
	    *x_compass = (rand() % (upper - lower + 1)) + lower;	
	}
	
}
```

The correction of the orientation of the proximity sensor is simulated with the *proximitySensorCorrection* function:

```c
void proximitySensorCorrection(short x_start_compass, short x_compass){
    
	short x_diff_compass = x_start_compass - x_compass;	
	int x_diff_compass_abs = abs((int)x_diff_compass);
	
	// If the proximity sensor is NOT correctly orientated
	if(x_diff_compass_abs > CORRECTION_THRESHOLD){
		
		//printf("[CONTROL] Sending to Arduino the indication of correcting the proximity sensor orientation\n");
		
	}
	
	// The proximity sensor is correctly orientated
	else{
	    //printf("The proximity sensor is correctly orientated\n"); 
	}
		
}
```

The base logic of the function is the same of the [real application](https://github.com/IlKaiser/IoT_Group-Project/blob/main/nucleo_code/README.md).

In the [main.c](https://github.com/IlKaiser/IoT_Group-Project/blob/main/evaluation/main.c), we need to define the **delay_control** sampling period, as well as the **CORRECTION_THRESHOLD**:

```c
#define CORRECTION_THRESHOLD 1

int delay_control = DELAY_CONTROL_BASE;
```

## Info thread

```c
static void* threadInfo(void* arg)
{
    (void)arg;
    
    srand(time(NULL));
	
	while(1)
	{
		int decision = rand() % 2;
		
		char* gpsInfo = getGpsInfoFromArduino(decision);
		
		if(strcmp(gpsInfo, "/") == 0){
			printf("[INFO] No info received!\n");
		}
		
		else{
		    printf("[INFO] %s\n",gpsInfo);
		}
			
		xtimer_sleep(delay_info);
	
	}
	
	return NULL;
}
```

The **info thread** is responsible for simulating the retrieval of **GPS** data. In particular, we simulate with a **random boolean decision** whether the **position** is available or not, by using the *getGpsInfoFromArduino* function, that we report below:

```c
char* getGpsInfoFromArduino(int decision){
    if(decision == 1)
		return GPS_INFO_REAL;
	else
	    return GPS_INFO_NOT_FOUND;
}
```

The function simply return some **fixed** GPS info if the decision is '1', nothing otherwise.

In the [main.c](https://github.com/IlKaiser/IoT_Group-Project/blob/main/evaluation/main.c), we need to define the **delay_info** sampling period:

```c
int delay_info = DELAY_INFO_BASE;
```

Also, in the [main.c](https://github.com/IlKaiser/IoT_Group-Project/blob/main/evaluation/main.c), we need to define the **GPS_INFO_REAL** and the **GPS_INFO_NOT_FOUND** constants:

```c
#define GPS_INFO_REAL                  "41.3456;19.3185;0.25"
#define GPS_INFO_NOT_FOUND             "/"
```

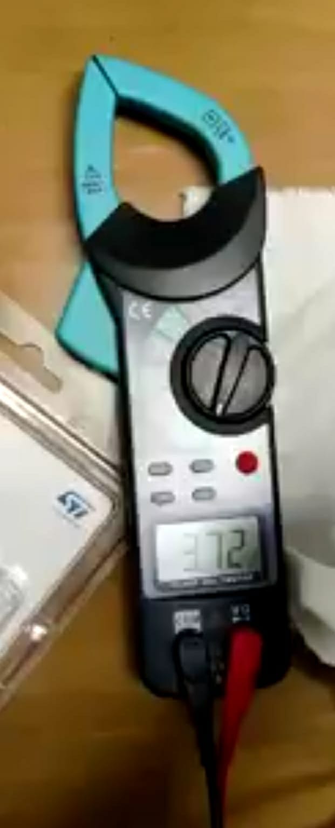
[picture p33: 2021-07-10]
imgs/tester_low_mode.jpeg

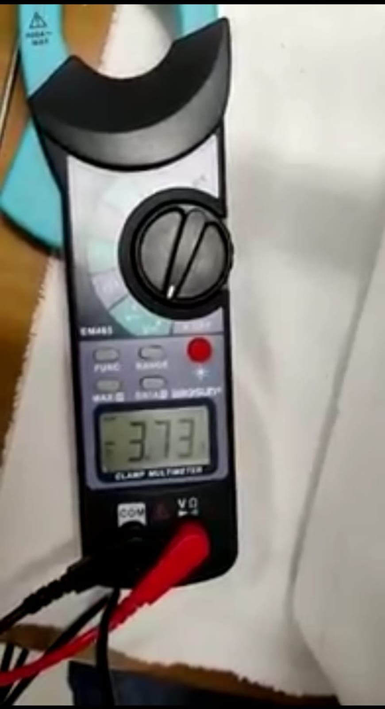
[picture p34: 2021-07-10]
imgs/tester_medium_mode.jpeg

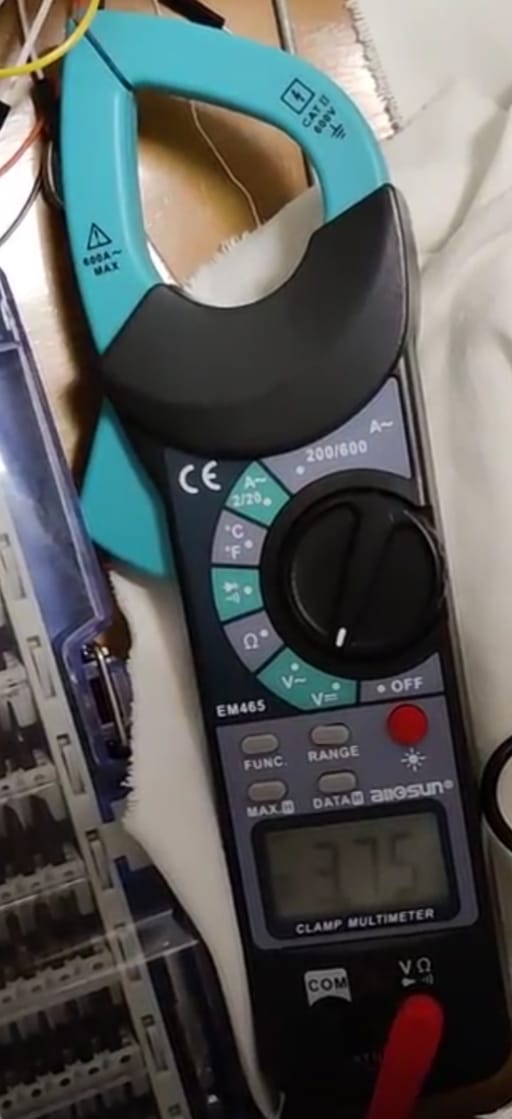
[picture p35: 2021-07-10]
imgs/high_consumption_tester.jpeg

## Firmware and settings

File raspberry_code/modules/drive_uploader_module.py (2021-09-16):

from __future__ import print_function
import os.path
from googleapiclient.discovery import build
from googleapiclient.http import MediaFileUpload
from google_auth_oauthlib.flow import InstalledAppFlow
from google.auth.transport.requests import Request
from google.oauth2.credentials import Credentials

# If modifying these scopes, delete the file token.json.
SCOPES = ['https://www.googleapis.com/auth/drive']

def drive_upload(photo_name="pic.jpg"):
    """Shows basic usage of the Drive v3 API.
    """
    creds = None
    # The file token.json stores the user's access and refresh tokens, and is
    # created automatically when the authorization flow completes for the first
    # time.
    try:
        if os.path.exists('modules/token.json'):
            creds = Credentials.from_authorized_user_file('modules/token.json', SCOPES)
        # If there are no (valid) credentials available, let the user log in.
        if not creds or not creds.valid:
            if creds and creds.expired and creds.refresh_token:
                creds.refresh(Request())
            else:
                flow = InstalledAppFlow.from_client_secrets_file(
                    'modules/credentials.json', SCOPES)
                creds = flow.run_local_server(port=0)
            # Save the credentials for the next run
            with open('modules/token.json', 'w') as token:
                token.write(creds.to_json())

        service = build('drive', 'v3', credentials=creds)

        # Call the Drive v3 API
        print("Begin Drive upload of "+ photo_name)
        file_metadata = {'name': photo_name,'parents':["1euot5RlQOXgl7bV8yZWktXFMeZJ8HsuG"]}
        media = MediaFileUpload(photo_name, mimetype='image/jpeg',resumable=True)
        file = service.files().create(body=file_metadata,
                                        media_body=media,
                                        fields='id').execute()

        print("Upload Complete!")
        
        file_id = file.get('id')
        print("Upload of "+ photo_name+" succeded!")
        print('File ID: %s' % file_id)
        print("Setting permssions...")
        
        def callback(request_id, response, exception):
            if exception:
                # Handle error
                print(exception)
                return -1
            else:
                print("Permission Id: %s" % response.get('id'))
                print("Drive upload fully succeced!")
        # Change permissions to anyone with the link can see the photo
        batch = service.new_batch_http_request(callback=callback)
        user_permission = {
            'type': 'anyone',
            'role': 'reader',
        }
        batch.add(service.permissions().create(
                fileId=file_id,
                body=user_permission,
                fields='id',
        ))
        batch.execute()
        return file_id
    
    except Exception as e:
        print("Error occurred!")
        print(e)
        return -1

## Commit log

2021-04-12 Add files via upload
    setup i2c basics
2021-04-13 added base communication with stm-32 by i2c
2021-04-13 added reading from proximity sensor
2021-04-14 Add files via upload
    added code in order to use 2 proximity sensor in the notification thread
2021-04-14 added second ultrasonic proximity sensor
2021-04-19 addedo motordc control
2021-04-19 added power management
2021-04-20 added step motor + code cleaning
2021-04-20 added correction tsHolds proxSens + code cleaning
    [main.c]
2021-04-22 fixed first reading mpu bug
    [main.c]
2021-04-22 created circuit folder
2021-04-22 added circuit's files
    [circuit.fzz]
2021-04-22 added wiring of components file
2021-04-22 updated wiring of components document
2021-04-22 Add Markdown for raspberry [WIP]
2021-04-23 added gps data receiving from Arduino
2021-04-24 fixed info bug "/"
    [main.c]
2021-04-28 modified proximity sensor correction
    [main.c]
2021-04-29 Update main.c
    added communication boat found to arduino
2021-05-03 Updates to raspberry code
2021-05-05 Raspberry Circuit
    [raspberry.fzz]
2021-05-10 Add circuit readme for raspberry
2021-05-10 Update raspberry readme [WIP]
2021-05-13 Huge QoL fixes on raspberry
    [bluetooth_module.py, drive_uploader_module.py, mqtt_module.py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]
2021-05-14 added shell input error handling
    [main.c]
2021-05-14 added thread timer for general mode
2021-05-19 Update id in the correct way
    [last_violation_id_module.py, safety_floater_check.py]
